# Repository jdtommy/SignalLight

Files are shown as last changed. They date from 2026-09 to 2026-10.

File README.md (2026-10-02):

# SignalLight 🚦

An intelligent status light project using the **Arduino Nano ESP32 (ESP32-S3)** and a **Windows Go (Golang)** desktop companion.

The light indicates your real-time availability:
- 🔴 **RED** (`D2`): In a meeting / Busy (automatically triggered by Zoom or hotkey)
- 🟡 **YELLOW** (`D3`): Not at desk / Away (**Default** on boot and failsafe disconnect)
- 🟢 **GREEN** (`D4`): Free / Available to talk

---

## ⚡ Hardware & Electrical Guide

### ⚠️ Critical Voltage & Wiring Safety Note
> [!WARNING]
> **ESP32-S3 logic levels are strictly 3.3V.**
> Although the Arduino Nano ESP32 board is powered by 5V (via USB-C or `VBUS`), the microcontroller GPIO pins (D2, D3, D4) are **NOT 5V tolerant** (maximum 3.6V).
> 
> If you connect a 10k pull-up resistor from **D3** to **5V**, you will place 5V directly onto an ESP32 GPIO pin. While a 10k resistor limits current, it violates the chip's absolute maximum ratings.
> 
> **Recommended Fix:**
> Connect your 10k pull-up resistor to the **`3V3`** pin on the Arduino header instead of the `5V` pin. This safely pulls D3 HIGH to 3.3V on power-up.

### 💡 Driving 12V LEDs from 3.3V Logic
The ESP32 GPIO pins output 3.3V logic and cannot directly drive 12V LEDs. You should use **Logic-Level N-Channel MOSFETs** (e.g., `IRLZ44N`, `2N7000`, `AO3400`) or a transistor/relay driver module:

```
                      +12V Supply
                           |
                           +--> [ + 12V LED Strip / Lamp ]
                                     |
                                     | (-) Cathode
                                   [ D ]  (Drain)
Arduino Pin (D2/D3/D4) --[100Ω]--> [ G ]  N-Channel Logic MOSFET
                                   [ S ]  (Source)
                                     |
                                    GND
                                     |
             Common GND <------------+------------> Arduino GND
```

#### Yellow Default Circuit:
To keep Yellow ON when the Arduino is disconnected or powered off:
- Place a **10kΩ pull-up resistor** between the **Gate (G)** of the Yellow MOSFET and the **3.3V** rail (or 5V rail if isolated from the GPIO pin by a resistor).
- When the Arduino boots, the firmware immediately drives D3 HIGH and D2/D4 LOW.

### 🖨️ Custom Driver PCB
[`jdtommy-status-indicator-copy-Gerbers-Versionba6d84cb/`](jdtommy-status-indicator-copy-Gerbers-Versionba6d84cb) (fab package) is a small 2-layer PCB export (from [Flux](https://flux.ai)) that replaces the breadboard wiring above with a real board. It mounts an Arduino Nano ESP32 and drives the three LED channels through three `2N3904`-family NPN transistors (instead of the MOSFETs described above — a valid alternative for a modest LED current draw) as low-side switches, with the same Yellow-defaults-on pull-up resistor design:

| Connector | Pin | Signal |
|---|-----|---|
| **CN1** (2-pin, power in) | 1 | GND |
| | 2 | +12V |
| **CN2** (4-pin, LED out) | 1 | +12V (common anode) |
| | 2 | Red cathode (via Q4, driven by D2, R2 = 1kΩ base resistor) |
| | 3 | Yellow cathode (via Q5, driven by D3, R3 = 1kΩ base resistor, **R1 = 10kΩ pull-up to 3.3V**) |
| | 4 | Green cathode (via Q6, driven by D4, R4 = 1kΩ base resistor) |
| **CN3** (2-pin, unpair button) | 1 | GND |
| | 2 | `D5` (firmware's internal pull-up; no external resistor) |

Board outline is roughly **19mm × 45mm**. Wire a normally-open momentary (panel-mount) button to **CN3**; holding it for 10 seconds unpairs the light (see the firmware notes in [ARCHITECTURE.md](ARCHITECTURE.md)).

> [!NOTE]
> **Bare PCB fabrication: ready to order.** `jdtommy-status-indicator-copy-Gerbers-Versionba6d84cb/` has properly formatted Gerber X2 files for all layers, a real Excellon drill file, and an IPC-D-356 bare-board test netlist — this is a standard fab package any house (JLCPCB, PCBWay, OSH Park, etc.) should accept directly. The `jdtommy-status-indicator.edif` netlist and the DXF/SVG plot folders are from the **previous** board revision (no CN3) and aren't needed for ordering.
>
> **Turnkey SMD assembly: not ready — fix the BOM first.** Every vendor BOM CSV in `BOM/` groups R1–R4 into a single line item labeled "1kΩ" (Flux's exporter grouped them by shared footprint and lost the distinct value). The correct values — confirmed in `pick_and_place.csv` — are **R1 = 10kΩ**, **R2/R3/R4 = 1kΩ**. If you submit a BOM as-is, R1 (the Yellow failsafe pull-up) would get placed as 1kΩ instead of 10kΩ: Yellow would still default on, just with ~10x more continuous current through that pull-up than intended. Split R1 into its own line before ordering assembly.
>
> Also note: **U2 (the Arduino Nano ESP32) can't be placed by any SMT line** — it's a whole dev board, not a stocked part, so it needs to be hand-soldered/socketed on regardless of which assembly path you use. The three JST connectors do have real LCSC part numbers (`C158012` for the 2-pin CN1/CN3, `C144395` for the 4-pin CN2) if you want an assembly house to place those.

---

## 📁 Project Structure

```
SignalLight/
├── arduino/
│   ├── SignalLight/
│   │   └── SignalLight.ino      # Arduino C++ sketch (BLE + Serial + Failsafe)
│   └── micropython/
│       └── main.py              # MicroPython equivalent (deprecated, see below)
├── windows/
│   ├── ble/                     # Bluetooth Low Energy (BLE) client
│   ├── hotkey/                  # Global Windows hotkeys (Ctrl+Shift+R/Y/G/A)
│   ├── serial/                  # USB Serial communication fallback
│   ├── server/                  # Web dashboard UI, REST API & Zoom webhook
│   ├── state/                   # State machine (Auto vs Manual, Red/Yellow/Green)
│   ├── zoom/                    # Zero-config Zoom meeting window detector
│   ├── go.mod / go.sum
│   ├── main.go                  # Windows application entry point
│   └── signallight.exe          # Compiled standalone Windows executable
├── installer/
│   └── SignalLight.iss          # Inno Setup script for the per-user installer
├── jdtommy-status-indicator.edif              # Driver PCB netlist (previous revision, no CN3)
├── status-indicator-dxf/                      # Driver PCB plot previews (DXF, not needed for ordering)
├── status-indicator-svg/                      # Driver PCB plot previews (SVG, not needed for ordering)
├── jdtommy-status-indicator-copy-Gerbers-Versionba6d84cb/   # Driver PCB fab package: Gerbers, drill file, BOMs, pick-and-place (see above)
└── README.md
```

---

## 🚀 Part 1: Arduino Firmware Setup

### Option A: Arduino IDE (Recommended)
1. Open the **Arduino IDE**.
2. Install the **Arduino ESP32 Boards** package:
   - Go to `Tools -> Board -> Boards Manager...`
   - Search for **Arduino Nano ESP32** and install.
3. Install the **ArduinoBLE** library:
   - Go to `Sketch -> Include Library -> Manage Libraries...`
   - Search for **ArduinoBLE** and click **Install**.
4. Open [`arduino/SignalLight/SignalLight.ino`](file:///C:/Users/jdtom/dev/SignalLight/arduino/SignalLight/SignalLight.ino).
5. Select `Tools -> Board -> Arduino Nano ESP32` and choose your COM port.
6. Click **Upload**.

### Option B: MicroPython (⚠️ Deprecated / Not Compatible)
[`arduino/micropython/main.py`](file:///C:/Users/jdtom/dev/SignalLight/arduino/micropython/main.py) is kept only as a reference starting point. It has no Auth
characteristic and cannot complete the PAIR/AUTH handshake the Windows app requires, so
pairing from the web dashboard will not work against it. Use Option A.

---

## 🖥️ Part 2: Windows Companion App (in Go)

The Windows app is written in **Go (Golang)**. It features:
1. **Bluetooth Low Energy (BLE)**: Automatically scans for and connects to the Nano ESP32 wirelessly.
2. **Zoom Meeting Detection**: Detects active Zoom meetings automatically with **zero configuration** by monitoring Zoom meeting windows (`ZPContentViewWnd`, `ZPFloatVideoWndClass`, and meeting titles).
3. **Screen Lock Detection:** Automatically detects when you lock your Windows workstation (<kbd>Win</kbd> + <kbd>L</kbd> or idle screen timeout):
   - Automatically switches to 🟡 **YELLOW (Away)** when locked.
   - Automatically restores 🟢 **GREEN (Available)** when unlocked.
   - Priority rule: 🔴 **Zoom Meeting (RED)** always takes precedence over the lock screen.
4. **Global Hotkeys**:
   - <kbd>Ctrl</kbd> + <kbd>Shift</kbd> + <kbd>G</kbd> : Set **GREEN** (Free / Available)
   - <kbd>Ctrl</kbd> + <kbd>Shift</kbd> + <kbd>Y</kbd> : Set **YELLOW** (Away / Not at Desk)
   - <kbd>Ctrl</kbd> + <kbd>Shift</kbd> + <kbd>R</kbd> : Set **RED** (Busy / In Meeting)
   - <kbd>Ctrl</kbd> + <kbd>Shift</kbd> + <kbd>A</kbd> : Set **AUTO** (Resume syncing with Zoom & Lock)
5. **Windows System Tray Icon:** A live, color-coded icon in your taskbar notification area:
   - Dynamic icon color: 🟢 Green, 🟡 Yellow, or 🔴 Red matching current status.
   - Click to open quick menu:
     - View current status & mode
     - Force Green (Available)
     - Force Yellow (Away)
     - Force Red (Busy)
     - Enable Auto Mode (Sync with Zoom & Lock)
     - Open Web Dashboard
     - Exit application
6. **Interactive Web Dashboard**: Automatically assigns an open local port (e.g. `http://localhost:9439`), displayed on startup and saved to config so bookmarks stay valid. Visit the dashboard to pair devices, see real-time status, and control the light from any browser.
7. **Fail-safe Heartbeat**: Continuously pings the Arduino. If your PC goes to sleep or disconnects, the Arduino automatically defaults back to **YELLOW** after 15 seconds.

### Running the App

#### Method 1: Installer (Recommended)
Download `SignalLight-Setup-<version>.exe` from the [latest GitHub Release](https://github.com/jdtommy/SignalLight/releases/latest) and run it. It's signed, needs no admin rights, and installs just for you to `%LOCALAPPDATA%\Programs\SignalLight`. It adds a Start menu shortcut and, unless you untick it, starts SignalLight when you sign in. Uninstall from **Settings → Apps → Installed apps**; it asks whether to keep your pairing.

The installed app has no console window: it lives in the system tray, and its log is at `%LOCALAPPDATA%\SignalLight\signallight.log`. Only one copy runs at a time; launching it again opens the dashboard.

#### Method 2: Running from Source (Development)
This bypasses Windows 11 Smart App Control policies without requiring code-signing certificates:
```powershell
cd C:\Users\jdtom\dev\SignalLight\windows
go run .
```
Or simply double-click [`windows/run.bat`](file:///C:/Users/jdtom/dev/SignalLight/windows/run.bat) or run [`windows/run.ps1`](file:///C:/Users/jdtom/dev/SignalLight/windows/run.ps1).

#### Method 3: Standalone Binary
Download the signed `signallight.exe` from the [latest GitHub Release](https://github.com/jdtommy/SignalLight/releases/latest) and run it from any folder (no install, no startup entry), or build your own from source:
```powershell
cd C:\Users\jdtom\dev\SignalLight\windows
.\signallight.exe
```
> [!NOTE]
> Binaries attached to GitHub Releases are signed with a publicly-trusted Authenticode certificate (via Azure Trusted Signing), so Windows 11 **Smart App Control (SAC)** should allow them without a warning. A binary you compile yourself locally (`go build`/`go run`) is **not** signed — signing requires a live call to Azure with valid credentials — so SAC may still block a self-built `.exe`. If it does, run via `go run .` or download the signed release instead.

#### Command Line Options
| Flag | Default | Description |
|---|---|---|
| `-ble` | `true` | Connect to Arduino over Bluetooth Low Energy |
| `-device` | `""` | BLE advertised device name (overrides config) |
| `-serial` | `""` | Optional USB COM port (e.g. `COM3` or `auto`) if using USB cable |
| `-port` | `""` | Web dashboard port (default: auto-allocated open port, e.g. 9120-9900, saved in config.json) |
| `-interval` | `1s` | Zoom meeting polling interval |

---

## 📋 Future Roadmap & TODO
- [x] **Binary Code Signing**: `signallight.exe` attached to GitHub Releases is signed via [Azure Trusted Signing](https://azure.microsoft.com/en-us/products/artifact-signing) (Public Trust, individual developer), so it should run under Smart App Control without a warning.
- [x] **Automated release signing**: pushing a `vX.Y.Z` tag runs [`.github/workflows/release.yml`](.github/workflows/release.yml), which tests, builds, signs, and verifies `signallight.exe` and the installer, compiles the light's firmware, then attaches them all to a **draft** release. Review the notes and publish. Azure sign-in uses GitHub OIDC, so no Azure secret is stored in GitHub.
- [x] **Installer**: signed per-user Inno Setup installer ([`installer/SignalLight.iss`](installer/SignalLight.iss)), built by the release workflow.

**Firmware updates over Bluetooth** (click-to-update from the dashboard; design and rationale in [docs/FIRMWARE_UPDATES.md](docs/FIRMWARE_UPDATES.md)):
- [x] Prototype BLE transfer throughput on ArduinoBLE: ~47 KB/s with flash writes, so the ~469KB firmware takes ~10s; no NimBLE migration needed
- [x] Firmware reports its version (read-only characteristic `19B10003`); dashboard shows it
- [x] Release workflow compiles the firmware with `arduino-cli` and attaches `signallight-firmware-<version>.bin` + `.sha256`
- [x] Firmware update receiver: chunk/ack protocol, `Update` library, "updating" LED pattern, rollback self-check (a ~500KB update takes ~10s)
- [x] Windows update client + dashboard UI: GitHub check, manual `.bin` upload, progress, retry
- [ ] (Optional) USB recovery flashing via `dfu-util`

**Later:**
- [ ] Firmware signing (CI signs, light verifies before switching)
- [ ] Windows app self-update from GitHub Releases
- [ ] Automatic idle-time firmware updates

---

## 🔗 Optional: Zoom Webhook Integration
The local desktop detector works without any setup. If you also want cloud-level presence notifications from Zoom:
1. Create a **Server-to-Server OAuth** or **Webhook Only** app in the [Zoom App Marketplace](https://marketplace.zoom.us/).
2. Set the Webhook endpoint URL to: `https://<your-public-url>/webhook/zoom`.
3. Subscribe to events: `meeting.started`, `meeting.ended`, `user.presence_status_updated`.
4. Start `signallight.exe` with your secret token:
   ```powershell
   .\signallight.exe -zoom-secret="YOUR_ZOOM_SECRET_TOKEN"
   ```

---

## 📄 License
MIT — see [LICENSE](LICENSE).

## 🔒 Privacy & Code Signing
- [Privacy Policy](PRIVACY.md) — SignalLight collects no data; everything runs locally.
- [Code Signing Policy](CODE_SIGNING_POLICY.md) — official repository, signed artifacts, and release process.

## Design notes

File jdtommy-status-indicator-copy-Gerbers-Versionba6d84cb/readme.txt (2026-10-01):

Project Name: Status Indicator Copy
Project Version: #ba6d84cb
Project Url: https://www.flux.ai/jdtommy/status-indicator-copy~ga

Project Description:
Welcome to your new project. Imagine what you can build here.

Index:

Bottom Copper (Gerber): status-indicator-copy-b_cu.gbr
Bottom Solder Mask (Gerber): status-indicator-copy-b_mask.gbr
Bottom Solder Paste (Gerber): status-indicator-copy-b_paste.gbr
Bottom Silkscreen (Gerber): status-indicator-copy-b_silks.gbr
Board Outline (Gerber): status-indicator-copy-edge_cuts.gbr
Top Copper (Gerber): status-indicator-copy-f_cu.gbr
Top Solder Mask (Gerber): status-indicator-copy-f_mask.gbr
Top Solder Paste (Gerber): status-indicator-copy-f_paste.gbr
Top Silkscreen (Gerber): status-indicator-copy-f_silks.gbr
Drill Holes (Excellon): status-indicator-copy.drl
Electrical Test Netlist (IPC-D-356): status-indicator-copy.d356
Component Positions, for assembly (Pick and Place, CSV): pick_and_place.csv

Bill of Materials: multiple versions are provided optimized for various contract manufacturers:

Bill of Materials (AdvancedCircuits): BOM/jdtommy-status-indicator-copy-BOM-Vba6d84cb-AdvancedCircuits.csv
Bill of Materials (AllPCB): BOM/jdtommy-status-indicator-copy-BOM-Vba6d84cb-AllPCB.csv
Bill of Materials (Elecrow): BOM/jdtommy-status-indicator-copy-BOM-Vba6d84cb-Elecrow.csv
Bill of Materials (Eurocircuits): BOM/jdtommy-status-indicator-copy-BOM-Vba6d84cb-Eurocircuits.csv
Bill of Materials (Flux): BOM/jdtommy-status-indicator-copy-BOM-Vba6d84cb-Flux.csv
Bill of Materials (JLCPCB): BOM/jdtommy-status-indicator-copy-BOM-Vba6d84cb-JLCPCB.csv
Bill of Materials (PCBWay): BOM/jdtommy-status-indicator-copy-BOM-Vba6d84cb-PCBWay.csv
Bill of Materials (Seeed): BOM/jdtommy-status-indicator-copy-BOM-Vba6d84cb-Seeed.csv

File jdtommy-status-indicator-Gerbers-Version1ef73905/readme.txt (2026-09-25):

Project Name: Status Indicator Copy
Project Version: #1ef73905
Project Url: https://www.flux.ai/jdtommy/status-indicator-copy~ga

Project Description:
Welcome to your new project. Imagine what you can build here.

Index:

Bottom Copper (Gerber): status-indicator-copy-b_cu.gbr
Bottom Solder Mask (Gerber): status-indicator-copy-b_mask.gbr
Bottom Solder Paste (Gerber): status-indicator-copy-b_paste.gbr
Bottom Silkscreen (Gerber): status-indicator-copy-b_silks.gbr
Board Outline (Gerber): status-indicator-copy-edge_cuts.gbr
Top Copper (Gerber): status-indicator-copy-f_cu.gbr
Top Solder Mask (Gerber): status-indicator-copy-f_mask.gbr
Top Solder Paste (Gerber): status-indicator-copy-f_paste.gbr
Top Silkscreen (Gerber): status-indicator-copy-f_silks.gbr
Drill Holes (Excellon): status-indicator-copy.drl
Electrical Test Netlist (IPC-D-356): status-indicator-copy.d356
Component Positions, for assembly (Pick and Place, CSV): pick_and_place.csv

Bill of Materials: multiple versions are provided optimized for various contract manufacturers:

Bill of Materials (AdvancedCircuits): BOM/jdtommy-status-indicator-copy-BOM-V1ef73905-AdvancedCircuits.csv
Bill of Materials (AllPCB): BOM/jdtommy-status-indicator-copy-BOM-V1ef73905-AllPCB.csv
Bill of Materials (Elecrow): BOM/jdtommy-status-indicator-copy-BOM-V1ef73905-Elecrow.csv
Bill of Materials (Eurocircuits): BOM/jdtommy-status-indicator-copy-BOM-V1ef73905-Eurocircuits.csv
Bill of Materials (Flux): BOM/jdtommy-status-indicator-copy-BOM-V1ef73905-Flux.csv
Bill of Materials (JLCPCB): BOM/jdtommy-status-indicator-copy-BOM-V1ef73905-JLCPCB.csv
Bill of Materials (PCBWay): BOM/jdtommy-status-indicator-copy-BOM-V1ef73905-PCBWay.csv
Bill of Materials (Seeed): BOM/jdtommy-status-indicator-copy-BOM-V1ef73905-Seeed.csv

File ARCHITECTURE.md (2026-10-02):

# SignalLight — Architecture & Technical Reference

This document details the underlying software architecture, communication protocols, state machines, and concurrency patterns used in **SignalLight**.

---

## 1. Bluetooth Low Energy (BLE) Protocol

The Arduino Nano ESP32 operates as a **GATT Server (Peripheral)**, and the Windows Go desktop companion operates as a **GATT Client (Central)**.

### GATT Service & Characteristics

```
Service: 19B10000-E8F2-537E-4F6C-D104768A1214
 ├── Characteristic 19B10001 (Control) [Read | Write | WriteWithoutResponse | Notify] (1 byte)
 ├── Characteristic 19B10002 (Auth)    [Read | Write | Notify] (UTF-8 String, max 64 bytes)
 ├── Characteristic 19B10003 (Version) [Read] (UTF-8 String, max 32 bytes)
 ├── Characteristic 19B10004 (Update control) [Write] (UTF-8 String, max 100 bytes)
 ├── Characteristic 19B10005 (Update status)  [Read | Notify] (UTF-8 String, max 64 bytes)
 └── Characteristic 19B10006 (Update data)    [Write | WriteWithoutResponse] (max 512 bytes)
```

#### Firmware Update Characteristics (`19B10004`–`19B10006`)
Bluetooth firmware updates: `BEGIN`/`END`/`ABORT` on control, replies and cumulative ACKs on status, sequence-numbered image chunks on data. Only a paired light with an authenticated connection accepts them. A new image must be confirmed by an authenticated connection within 5 minutes of its first boot or the bootloader rolls it back. Full protocol in [docs/FIRMWARE_UPDATES.md](docs/FIRMWARE_UPDATES.md).

#### Version Characteristic (`19B10003`)
Read-only firmware version string, readable without `AUTH` (e.g. `1.2.0`; `dev` for Arduino IDE builds). Set at build time with `-DSIGNALLIGHT_VERSION="x.y.z"` (release builds pass it via `arduino-cli --build-property "compiler.cpp.extra_flags=..."`). Firmware older than this characteristic doesn't have it; the app shows the version as unknown and still connects.

#### Control Characteristic (`19B10001`)
Used for state synchronization, manual commands, and heartbeat pings:
- `'R'` (0x52): In Meeting / Busy.
- `'Y'` (0x59): Away / Workstation Locked.
- `'G'` (0x47): Free / Available.
- `'0'` (0x30): All Off.
- `'P'` (0x50): Heartbeat Ping.
- `'?'` (0x3F): Status Query (returns current color via Serial / BLE read).

#### Auth Characteristic (`19B10002`)
Used for discovery, secure pairing handshakes, and unpairing:
- `PAIR:<FriendlyName>:<SharedSecret>`: Initial pairing command when device is in factory unpaired mode. Returns `PAIR_OK` or error (`ERR:ALREADY_PAIRED`, `ERR:BAD_FORMAT`). `SharedSecret` is generated automatically by the Windows app (random 128-bit value) — the user never sees or types it, only the friendly name.
- `AUTH:<SharedSecret>`: Authentication challenge response sent by Central upon each connection. Returns `AUTH_OK` or `AUTH_FAIL`.
- `UNPAIR`: Factory resets device credentials and reboots into unpaired mode. Returns `UNPAIR_OK`.
- `STATUS?`: Queries device mode. Returns `STATUS:PAIRED` or `STATUS:UNPAIRED`.

---

## 2. Interaction Sequence Diagrams

### Initial Pairing Sequence
```
Central (Windows)                            Peripheral (Arduino Nano ESP32)
       │                                                    │
       │  Scan nearby BLE devices                           │
       │───────────────────────────────────────────────────>│
       │  Advertising: "SignalLight-69F5" (Yellow pulse)    │
       │<───────────────────────────────────────────────────│
       │                                                    │
       │  Connect                                           │
       │───────────────────────────────────────────────────>│
       │  Write (Auth): "PAIR:Office Desk:MySecret123"      │
       │───────────────────────────────────────────────────>│
       │                                                    │ Saves to NVS flash:
       │                                                    │ paired=true, name="Office Desk",
       │                                                    │ secret="MySecret123", active_color='G'
       │  Notify (Auth): "PAIR_OK"                          │
       │<───────────────────────────────────────────────────│
       │                                                    │
       │  Write (Control): 'G'                              │
       │───────────────────────────────────────────────────>│
       │                                                    │ Physical Green LED illuminated
```

---

### Reconnection & State Sync Sequence
```
Central (Windows)                            Peripheral (Arduino Nano ESP32)
       │                                                    │
       │  Connect to "Office Desk" (E8:F6:0A:BE:69:F5)      │
       │───────────────────────────────────────────────────>│
       │                                                    │ isCentralConnected = true
       │  Write (Auth): "AUTH:MySecret123"                  │ isAuthenticated = false (starts 4s timer)
       │───────────────────────────────────────────────────>│
       │                                                    │ Verifies secret against NVS flash
       │                                                    │ isAuthenticated = true
       │                                                    │ applyColor(activeColor) -> Instant Green!
       │  Notify (Auth): "AUTH_OK"                          │
       │<───────────────────────────────────────────────────│
       │                                                    │
       │  Write (Control): Current Desktop State (e.g. 'G') │
       │───────────────────────────────────────────────────>│
       │                                                    │ Confirms activeColor = 'G'
       │                                                    │
       │  Periodic Heartbeat every 3s                       │
       │  Write (Control): 'G'                              │
       │───────────────────────────────────────────────────>│
       │                                                    │ lastHeartbeatTime = millis()
```

---

### Disconnect Grace Period & Watchdog Handling
```
Scenario A: Brief RF Interference (2 seconds)
Central (Windows)                            Peripheral (Arduino Nano ESP32)
       │                                                    │
       │  (Link drop / renegotiation)                       │
       │- - - - - - - - - - - - - - - - - - - - - - - - - ->│
       │                                                    │ blePeripheralDisconnectHandler()
       │                                                    │ disconnectTime = millis()
       │                                                    │ GRACE PERIOD: 45s timer starts.
       │                                                    │ Light STAYS GREEN (No flicker!)
       │  Reconnects after 2s + Auth Handshake              │
       │───────────────────────────────────────────────────>│
       │                                                    │ isAuthenticated = true
       │                                                    │ Active Green maintained seamlessly!

Scenario B: PC Power Off / Prolonged Absence (> 45s)
       │  PC Powers Off                                     │
       │- - - - - - - - - - - - - - - - - - - - - - - - - ->│
       │                                                    │ 45s Disconnect Grace expires.
       │                                                    │ displayedColor switches to YELLOW.
       │                                                    │ (activeColor remains 'G' in flash)
       │                                                    │
       │  PC Boots next morning & reconnects                │
       │───────────────────────────────────────────────────>│
       │  "AUTH:MySecret123"                                │
       │───────────────────────────────────────────────────>│
       │                                                    │ Restores activeColor ('G') immediately!
```

---

## 3. Firmware State Management (`arduino/`)

### Flash (NVS) Layout (`Preferences` namespace: `signallight`)
- `paired` (`bool`): `true` if device has completed initial setup.
- `name` (`String`): Advertised device name (e.g. `"Office Desk"`).
- `secret` (`String`): Shared authorization secret.
- `active_color` (`char`): Last active user color (`'R'`, `'G'`, `'Y'`, `'0'`). Restored on boot.

### Physical Unpair Button (`D5`)
A momentary button from `D5` to GND (`INPUT_PULLUP`, 50ms debounce). Holding it freezes the LEDs on solid red; after 10 seconds the light flashes red 3 times and factory resets (same `factoryReset()` as the `UNPAIR` command). Releasing early cancels and restores `activeColor`. This replaced an older reset-button double-press scheme (`rst_armed` flash flag), which could be falsely triggered by any quick power cycle and wrote to flash on every boot.

### Two-Tier Color Architecture
```
             ┌────────────────────────────────────────────────────────┐
             │                      activeColor                       │
             │           (User / Host Intended State: G/R/Y/0)        │
             └───────────┬────────────────────────────────┬───────────┘
                         │                                │
            Authenticated Handshake               45s Disconnect Timeout
                         │                                │
                         ▼                                ▼
             ┌───────────────────────┐        ┌───────────────────────┐
             │    displayedColor     │        │    displayedColor     │
             │     (Active Color)    │        │       (Yellow)        │
             └───────────────────────┘        └───────────────────────┘
```

---

## 4. Desktop Companion Architecture (`windows/`)

### Concurrency Model
The Go desktop companion coordinates several concurrent goroutines:

```
  ┌─────────────────────────────────────────────────────────────────────────┐
  │                              main() Goroutine                           │
  │                   Initializes subsystems & enters runtime               │
  └───────┬─────────────────┬──────────────────┬─────────────────┬──────────┘
          │                 │                  │                 │
          ▼                 ▼                  ▼                 ▼
   lifecycleLoop()    detectorLoop()     sessionLoop()     httpServer()
     (BLE Central)     (Win32 Zoom)      (Win32 Lock)      (REST / Web)
```

1. **`lifecycleLoop()` (BLE)**: Runs on an OS-locked thread (`runtime.LockOSThread()`) with initialized WinRT COM (`ole.RoInitialize(1)`). Continuously scans, connects, authenticates, and hands connection to `connectionLoop()`.
2. **`connectionLoop()` (BLE)**: Maintains the active link:
   - Evaluates a 3-second ticker for state synchronization and heartbeats.
   - Listens to `c.sendChan` for instantaneous priority color changes from the state manager.
   - Monitors OS link status via `device.Connected()` and abort signals from `SetConnectHandler`.
3. **`detectorLoop()` (Zoom)**: Polls every 1s using Win32 `EnumWindows` and `GetClassNameW` to detect active meeting video windows.
4. **`sessionLoop()` (Lock)**: Creates a hidden Win32 message window and registers for `WTSRegisterSessionNotification`.
5. **`httpServer()` (Web)**: Serves dashboard and REST API on a dynamic port without blocking core workers.

### State Evaluation Priority
The central `StateManager` computes colors in `AUTO` mode using strict hierarchy:
```
1. Not Connected   -> OFF
2. Zoom in Meeting -> RED
3. Screen Locked   -> YELLOW
4. Available       -> GREEN
```
Manual overrides bypass automatic evaluation until returning to `AUTO` via hotkey (<kbd>Ctrl</kbd> + <kbd>Shift</kbd> + <kbd>A</kbd>) or web dashboard.

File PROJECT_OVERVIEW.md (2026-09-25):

# SignalLight — Project Overview

An intelligent, wireless availability and presence indicator for home offices and shared workspaces.

---

## 🎯 Purpose & Philosophy

In modern remote and hybrid workspaces, interruptions during focused work or sensitive video meetings create friction. **SignalLight** solves this by physically broadcasting your real-time status to family members, housemates, or colleagues via a high-visibility, 3-color physical light:

- 🔴 **RED**: In a meeting or actively busy.
- 🟡 **YELLOW**: Away from desk or workstation locked.
- 🟢 **GREEN**: Free, available, and open to conversation.

The system is designed with a **zero-effort, automatic-first** philosophy:
- When a Zoom call starts, the light turns **RED** without touching a button.
- When you lock your screen (<kbd>Win</kbd> + <kbd>L</kbd>) or step away, the light turns **YELLOW**.
- When you unlock your screen, it seamlessly restores **GREEN**.
- Global hotkeys, a system tray icon, and a browser-based web dashboard provide instant manual overrides when needed.

---

## 🏗️ High-Level System Architecture

```
 +-------------------------------------------------------------------+
 |                        WINDOWS WORKSTATION                        |
 |                                                                   |
 |  [Zoom Meeting]     [Screen Lock]     [Global Hotkeys]            |
 |         │                 │                  │                    |
 |         ▼                 ▼                  ▼                    |
 |  ┌─────────────────────────────────────────────────────────────┐  |
 |  │                State Manager (windows/state)                │  |
 |  │     Priority: Zoom (RED) > Lock (YELLOW) > Free (GREEN)     │  |
 |  └──────────────────────────────┬──────────────────────────────┘  |
 |                                 │                                 |
 |                                 ▼                                 |
 |  ┌─────────────────────────────────────────────────────────────┐  |
 |  │              BLE Central Client (windows/ble)               │  |
 |  │        Auto-discovery, Security Handshake, Heartbeats       │  |
 |  └──────────────────────────────┬──────────────────────────────┘  |
 |                                 │                                 |
 |  [Web Dashboard (localhost:9439)] [Tray Icon (Green/Yellow/Red)]  |
 +─────────────────────────────────┼─────────────────────────────────+
                                   │
                                   │ Bluetooth Low Energy (2.4 GHz)
                                   ▼
 +-------------------------------------------------------------------+
 |                    SIGNAL LIGHT HARDWARE UNIT                     |
 |                                                                   |
 |  ┌─────────────────────────────────────────────────────────────┐  |
 |  │              Arduino Nano ESP32 (ESP32-S3)                  │  |
 |  │    - BLE Peripheral Service (19B10000-...)                  │  |
 |  │    - Flash Persistence (NVS) for Pairing & Color Memory     │  |
 |  │    - 45s Disconnect Grace Period & Failsafe Watchdog        │  |
 |  └──────────┬───────────────────┬───────────────────┬──────────┘  |
 |             │ (Pin D2: RED)     │ (Pin D3: YELLOW)  │ (Pin D4: GREEN)
 |             ▼                   ▼                   ▼             |
 |      [MOSFET Driver]     [MOSFET Driver]     [MOSFET Driver]      |
 |             │                   │                   │             |
 |             ▼                   ▼                   ▼             |
 |       🔴 RED LIGHT        🟡 YELLOW LIGHT     🟢 GREEN LIGHT      |
 |                                                                   |
 +-------------------------------------------------------------------+
```

---

## 📦 Repository Structure

```
SignalLight/
├── AGENTS.md                    # Detailed guide and rules for AI assistants
├── ARCHITECTURE.md              # Technical protocols, state diagrams & security
├── PROJECT_OVERVIEW.md          # Comprehensive project description (this file)
├── README.md                    # Quickstart and user manual
│
├── arduino/
│   ├── SignalLight/
│   │   └── SignalLight.ino      # Main Arduino C++ firmware (ESP32-S3 BLE)
│   └── micropython/
│       └── main.py              # MicroPython reference firmware
│
└── windows/
    ├── ble/                     # Windows WinRT BLE client & connection lifecycle
    ├── config/                  # Configuration manager (%APPDATA%\SignalLight)
    ├── hotkey/                  # Windows global hotkey listener
    ├── serial/                  # USB Serial communication fallback
    ├── server/                  # Embedded HTTP server & Web Dashboard UI
    ├── session/                 # Windows workstation lock/unlock detector
    ├── state/                   # Central availability state machine
    ├── third_party/bluetooth/   # Forked bluetooth library with WinRT timeout patch
    ├── tray/                    # Dynamic Windows system tray notification icon
    ├── zoom/                    # Zero-config Win32 Zoom meeting window detector
    ├── main.go                  # Windows entry point
    ├── run.bat / run.ps1        # One-click launch scripts (source execution)
    └── signallight.exe          # Standalone compiled executable
```

---

## 💡 Key Features

### 1. Hands-Free Zoom Sync
No Zoom OAuth or cloud tokens required. The Windows desktop daemon monitors native Zoom video window handles (`ZPContentViewWnd`, `ZPFloatVideoWndClass`) and window titles. As soon as you join a meeting or breakout room, the light switches to Red in less than a second.

### 2. Workstation Lock Detection
Monitors Windows session changes (`WM_WTSSESSION_CHANGE`). When you lock your screen (<kbd>Win</kbd> + <kbd>L</kbd>) or your PC locks after idle timeout, the light switches to Yellow (Away). Returning and unlocking your screen restores Green (Available).

### 3. Resilient BLE with Grace Period
- **45-Second Disconnect Grace:** If Bluetooth experiences momentary RF interference or your laptop renegotiates connection parameters, the light stays solid Green. It only switches to Yellow if disconnected continuously for more than 45 seconds.
- **Instant Reconnection:** When your laptop comes back into range, the Arduino automatically and immediately restores the active color.
- **Fail-Safe Watchdog:** If your PC shuts down, the Arduino detects the absence of heartbeats and falls back to Yellow.

### 4. Interactive Web Dashboard
A modern, responsive web control interface runs on a dynamically allocated local port (e.g. `http://localhost:9439`). Features:
- Real-time live status indicator.
- Single-click color buttons (Green, Yellow, Red, Off).
- Auto mode toggle.
- BLE device scanner, pairing wizard, and unpair controls.

### 5. Multi-Color System Tray Applet
The application lives quietly in the Windows system tray with a dynamic icon colored Green, Yellow, or Red matching your real-time status. Right-clicking provides instant manual controls and direct dashboard access.

---

## ⚡ Hardware Specifications

| Component | Specification |
|---|---|
| **Microcontroller** | Arduino Nano ESP32 (ESP32-S3, Xtensa dual-core, 2.4 GHz BLE) |
| **Operating Voltage** | 5V via USB-C or VBUS; internal MCU logic is **strictly 3.3V** |
| **Logic Outputs** | `D2` (Red), `D3` (Yellow), `D4` (Green) at 3.3V logic level |
| **Power Switching** | Low-side N-Channel Logic MOSFETs (e.g., IRLZ44N, 2N7000, AO3400) |
| **External Light** | 12V LED indicator tower, lamp, or 12V LED strip segments |
| **Safety Circuit** | 10kΩ pull-up resistor from Yellow MOSFET Gate to **3.3V rail** (ensures Yellow on startup/power-off) |

---

## 🚀 Getting Started

1. **Flash the Arduino:** Open [`arduino/SignalLight/SignalLight.ino`](file:///C:/Users/jdtom/dev/SignalLight/arduino/SignalLight/SignalLight.ino) in the Arduino IDE and upload to your Arduino Nano ESP32.
2. **Launch the Windows App:**
   ```powershell
   cd C:\Users\jdtom\dev\SignalLight\windows
   .\run.bat
   ```
3. **Open Dashboard:** Navigate to `http://localhost:9439` (or the port displayed in the console) to complete initial pairing.

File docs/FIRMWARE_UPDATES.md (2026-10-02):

# Firmware Updates over Bluetooth (Design)

Status: **in progress** (see [TODO](#todo)). Goal: update the light's firmware from the Windows app over Bluetooth, with no USB cable and no Wi-Fi setup.

## Decisions

- **Transport:** Bluetooth (BLE), reusing the existing pairing and `AUTH` handshake.
- **Firmware sources:** the latest GitHub Release (normal path), plus a manual `.bin` upload in the dashboard for testing local builds.
- **Updates are click-to-install.** The dashboard shows "firmware vX available" and the user starts the update. No automatic updates for now.
- **Firmware signing is deferred.** The device will verify a SHA-256 of the image, but not a publisher signature yet. See [Later](#later).
- **Windows app self-update is out of scope** for this work.

## What the hardware already gives us

Checked against the installed core (`arduino:esp32` `2.0.18-arduino.5`, board `nano_nora`):

- **Two app slots.** The default partition table (`app3M_fat9M_fact512k_16MB`) has `app0` and `app1` (3MB each) plus `otadata`. The light keeps running from one slot while the new image is written to the other, then reboots into it. An interrupted update leaves the old firmware untouched.
- **Rollback is available.** The bootloader is built with `CONFIG_BOOTLOADER_APP_ROLLBACK_ENABLE=y`. **Catch:** the Arduino core marks a new image as good before `setup()` runs. To make rollback meaningful, the sketch must override `verifyRollbackLater()` to return `true`, then call `esp_ota_mark_app_valid_cancel_rollback()` only after its own self-check passes (BLE started, `loop()` reached). Otherwise the next reboot reverts to the previous image.

## Approach

**Device side: a small custom protocol on the existing ArduinoBLE stack, using the core's `Update` library for flash writes.** The ready-made BLE update libraries ([BLEOTA](https://github.com/gb88/BLEOTA), [NimBLEOta](https://github.com/h2zero/NimBLEOta)) use the NimBLE/Bluedroid stacks, and the sketch uses ArduinoBLE; two BLE stacks can't run at once. Their uploaders are Python/web/mobile, not Go, so the Windows side is custom either way. `Update` handles slot selection, writing, and switching the boot partition. Migrating the sketch to NimBLE stays an option if ArduinoBLE proves too slow (it's lighter and faster, but a bigger change).

**Protocol** (three characteristics on the existing service; device side in `handleOta` and friends in the sketch, app side in `windows/ota`):

| UUID | Name | Properties | Content |
|---|---|---|---|
| `19B10004-…` | Update control | Write | `BEGIN <size> <sha256 hex>`, `END`, `ABORT` |
| `19B10005-…` | Update status | Read, Notify | `READY`, `ACK <seq>`, `OK`, `ABORTED`, `ERR <reason>` |
| `19B10006-…` | Update data | Write, WriteWithoutResponse (512) | `[seq uint32 LE][image bytes]` |

1. `BEGIN <size> <sha256>`: only accepted from a paired light with an authenticated connection (`ERR NOT_AUTHENTICATED` otherwise). The device calls `Update.begin(size)` and replies `READY`.
2. Numbered data chunks sent with `WriteWithoutResponse`. The device requires chunks strictly in order (`ERR SEQ expected N got M` otherwise), writes them with `Update.write`, hashes them, and sends a cumulative `ACK <seq>` every 16 chunks and after the last one. The app keeps at most 32 chunks unacknowledged (see results below). Flow control borrows from Espressif's BLE OTA design and [esp-ota-ble](https://github.com/fl4p/esp-ota-ble).
3. `END`: the device checks the byte count and the SHA-256, then `Update.end()` (which validates the image and sets the boot partition), replies `OK`, and reboots a second later.
4. **Confirm:** the new firmware boots in the bootloader's pending-verify state (`verifyRollbackLater()` returns `true`). The first successful `AUTH` marks it valid. If no authenticated connection arrives within 5 minutes, the light rolls back to the previous firmware and reboots.

Any failure (disconnect, `ABORT`, 15 seconds without data, bad sequence, size or hash mismatch, flash error) aborts the update and leaves the current firmware untouched. The app starts over from `BEGIN`. Notifications are queued by the BLE handlers and sent from `loop()`.

**Must not trust Windows write results.** WinRT can report a BLE write as successful when it never reached the device (see the `writeControl` history in `windows/ble/client.go`). Progress must be driven by the device's acknowledgements and the final hash check, never by write calls returning without error.

**While updating:** the light shows a distinct pattern (e.g. blue on the onboard RGB LED), and ignores color commands and the heartbeat watchdog until it reboots or the update is aborted.

**Firmware publishing:** the release workflow compiles the sketch with `arduino-cli` for `arduino:esp32:nano_nora` and attaches `signallight-firmware-<version>.bin` and its SHA-256 to the draft release. The app compares the light's reported version with the latest release.

## Throughput prototype results (October 2026)

Measured with `arduino/BleThroughputTest` and `windows/cmd/blethroughput`: 128KB per run, Nano ESP32 to Windows 11. Every run delivered all data in order with a matching checksum.

- **Firmware is small:** the current SignalLight image is about **469KB** (`arduino-cli compile --fqbn arduino:esp32:nano_nora`), not the ~1.5MB first assumed.
- **MTU:** Windows negotiated **242**, so each write carries 239 bytes (235 of data after a 4-byte sequence number).

| Mode | KB/s | Time for 469KB |
|---|---|---|
| Acked writes (`Write`) | 2.0 | ~3m50s |
| No-response, window 4 | 7.3 | ~65s |
| No-response, window 8 | 14.8 | ~32s |
| No-response, window 16 | 27.3 | ~17s |
| No-response, window 32 | 54.7 | ~9s |
| No-response, window 32, with flash writes | 47.4 | ~10s |

**Conclusions:**
- **ArduinoBLE is fast enough. No NimBLE migration needed.**
- Speed is bound by the ACK round trip (about 65ms, steady across windows), not by link bandwidth: doubling the window doubles the speed. Acked writes pay that round trip on every write, which is why they are slow.
- Writing to flash costs only 2–13%.
- `WriteWithoutResponse` lost no data, even at window 32. When the device falls behind, the BLE link layer holds the sender back instead of dropping data (the ESP32 transport's 258-byte receive buffer blocks the controller until `loop()` reads it).
- **Use window 32** (device ACKs every 16 chunks) for the real protocol. Larger windows would likely be faster, but ~10s is already enough.

**Lessons for the real protocol:**
- **Put commands and replies on separate characteristics.** ArduinoBLE notifies subscribers of the value a central writes, so on a combined write+notify characteristic, the app receives its own commands back as if they were replies.
- On Windows, `adapter.Enable()` is just `RoInitialize`; calling `RoInitialize` yourself first makes `Enable()` fail with "Incorrect function" (`S_FALSE`).
- Pass `BLE.setLocalName()` a string that outlives `setup()`; ArduinoBLE stores the pointer.
- `Update.write` rejects an image whose first byte isn't `0xE9` (ESP image magic).

## TODO

1. ~~**Prototype throughput.**~~ Done: see results above. ArduinoBLE with a 32-chunk window sends the current firmware in about 10 seconds.
2. ~~**Firmware version reporting.**~~ Done: read-only characteristic `19B10003`, set from the `SIGNALLIGHT_VERSION` build define (`dev` for IDE builds). Release builds can set it with `arduino-cli compile --build-property "compiler.cpp.extra_flags=-DSIGNALLIGHT_VERSION=\"x.y.z\""` (verified). The Windows app discovers characteristics unfiltered so lights on older firmware still connect, and the dashboard shows the version.
3. ~~**CI builds firmware.**~~ Done: the release workflow's `firmware` job compiles with `arduino-cli` 1.5.1, pinned to `arduino:esp32@2.0.18-arduino.5` and `ArduinoBLE@2.1.0` (the versions used for local IDE builds), stamps the version from the tag, checks the version string is in the binary, and attaches `signallight-firmware-<version>.bin` (the app image, which starts with `0xE9`) plus a `.sha256`.
4. ~~**Device update receiver.**~~ Done (protocol above). Hardware test: a 503KB image installed in 9.5s, rebooted, and was confirmed on reconnect (`dev` → `0.9.0-ota-test`). Flashing over USB from the Arduino IDE afterwards still works (back to `dev`). blue onboard LED while updating (the external light keeps its color), rollback unless confirmed by an authenticated connection within 5 minutes. Windows side: the `windows/ota` package (unit-tested against a simulated light) and a test CLI, `go run ./cmd/otaflash <SignalLight.ino.bin>` (quit SignalLight first).
5. ~~**Windows update client and dashboard UI.**~~ Done: the dashboard's firmware panel (shown while a light is paired) shows the light's version, checks GitHub Releases for the newest release with firmware (every 6 hours while the dashboard is open, or on "Check for updates"), and offers "Update to vX", or "Install vX" for a light running a `dev` build. "Install from file…" sends a local `SignalLight.ino.bin`. Downloads are checked against the published `.sha256`. Progress comes from the light's ACKs; after the light reboots, the app waits up to 90 seconds for it to reconnect on the new version and reports the result. A failed update leaves the old firmware running, and clicking Update again starts over. Code: `windows/firmware` (release check and install job), `ble.Client.UpdateFirmware`, `/api/firmware*` in `windows/server`. Tested on hardware both ways: "Install from file…" with a local build, and "Update to 1.2.0" from the published v1.2.0 release (download, checksum, install, reconnect on the new version).
6. **USB recovery fallback (optional).** Flash over USB with `dfu-util` (the board's normal upload tool) if a light ever gets stuck.

## Later

- **Firmware signing.** CI signs the `.bin` (e.g. Ed25519) and the device verifies it against a public key built into the firmware before switching slots, so a compromised PC can't flash malicious firmware. Manual `.bin` uploads would then need signing too, or a developer-mode switch.
- **Windows app self-update** via the same GitHub Releases check.
- **Automatic (idle-time) firmware updates**, once click-to-update has proven reliable.

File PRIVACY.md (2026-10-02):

# Privacy Policy

SignalLight does not collect, transmit, or store any personal data on any server. Everything runs on your own computer and your own Arduino hardware (the only internet access is the firmware update check described below):

- Zoom meeting status is detected locally by scanning window titles on your PC — no Zoom account, API, or OAuth token is used.
- Windows lock/unlock state is detected locally via the OS.
- The web dashboard runs only on `localhost` and is not reachable from the network.
- Pairing info (BLE device address, name, and shared secret) is stored only in a local config file on your own machine (`%APPDATA%\SignalLight\config.json`), never transmitted elsewhere.

**Firmware update checks:** while the web dashboard is open and a light is paired, the app asks GitHub's public releases API (`api.github.com`) for newer light firmware, at most every 6 hours or when you click "Check for updates". When you click Update, it downloads the firmware file from GitHub. These requests carry no personal data, account, or identifier of yours or your light. As with any web request, GitHub sees your IP address; see [GitHub's privacy statement](https://docs.github.com/site-policy/privacy-policies/github-general-privacy-statement). The app makes no other internet requests.

**Optional Zoom webhook integration:** if you choose to configure a Zoom webhook (off by default), your own Zoom account sends meeting/presence events directly to a server you host and control. No third party operated by the SignalLight project is involved in that data flow.

This project has no analytics, crash reporting, or telemetry of any kind.

## Contact

Questions about this policy can be raised via a [GitHub issue](https://github.com/jdtommy/SignalLight/issues) on the project repository.

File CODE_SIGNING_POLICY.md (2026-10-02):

# Code Signing Policy

**Official repository:** https://github.com/jdtommy/SignalLight — this is the only source of authentic SignalLight releases.

**Signed artifacts:** the compiled Windows executable (`signallight.exe`) attached to each [GitHub Release](https://github.com/jdtommy/SignalLight/releases).

**Signing method:** binaries are signed using [Azure Trusted Signing](https://azure.microsoft.com/en-us/products/artifact-signing) under a Public Trust, individual-developer certificate profile. Each signature is issued by a Microsoft-managed CA chain ("Microsoft ID Verified CS EOC CA 04" or successor) and RFC 3161 timestamped, so signatures remain valid independent of the short-lived signing certificate's own expiry.

**Release process:** the repository owner ([@jdtommy](https://github.com/jdtommy)) starts a release by pushing a `v*` tag. The [release workflow](.github/workflows/release.yml) builds and signs `signallight.exe` on GitHub-hosted runners and attaches it to a draft release, which the owner reviews and publishes. The workflow signs in to Azure via GitHub OIDC; Azure only accepts tokens for this repository's `release` environment (restricted to `v*` tags and `main`), and that identity holds only the signer role on this one signing account. No other individuals have release or signing authority.

**Privacy:** see [PRIVACY.md](./PRIVACY.md).

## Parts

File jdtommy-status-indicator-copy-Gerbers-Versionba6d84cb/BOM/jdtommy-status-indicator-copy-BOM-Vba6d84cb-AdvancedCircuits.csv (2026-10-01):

Component Description | QTY | Ref Des | Mfg P/N # | Manufacturer | Distributor P/N #
Wire To Board / Wire To Wire Connector, CONN-TH_B2B-XH-A-LF-SN | 2 | CN1,CN3 | B2B-XH-A(LF)(SN) | JST
Wire To Board / Wire To Wire Connector, CONN-TH_B4B-XH-A-LF-SN | 1 | CN2 | B4B-XH-A(LF)(SN) | JST
Transistor | 3 | Q4,Q5,Q6 | MMBT3904LT1G | onsemi
Resistor, 1kΩ, SMD_1206_3216Metric | 4 | R1,R2,R3,R4 | 1206
Development Board | 1 | U2 | ABX00083 | Arduino

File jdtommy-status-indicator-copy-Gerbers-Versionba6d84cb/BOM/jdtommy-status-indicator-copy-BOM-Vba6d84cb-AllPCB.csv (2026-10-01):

Item # | Ref Des | Qty | Manufacturer | Mfg Part # | Description / Value | Package | Type | Your Instructions / Notes
1 | CN1,CN3 | 2 | JST | B2B-XH-A(LF)(SN) | Wire To Board / Wire To Wire Connector, CONN-TH_B2B-XH-A-LF-SN | CONN-TH_B2B-XH-A-LF-SN
2 | CN2 | 1 | JST | B4B-XH-A(LF)(SN) | Wire To Board / Wire To Wire Connector, CONN-TH_B4B-XH-A-LF-SN | CONN-TH_B4B-XH-A-LF-SN
3 | Q4,Q5,Q6 | 3 | onsemi | MMBT3904LT1G | Transistor
4 | R1,R2,R3,R4 | 4 |  | 1206 | Resistor, 1kΩ, SMD_1206_3216Metric
5 | U2 | 1 | Arduino | ABX00083 | Development Board

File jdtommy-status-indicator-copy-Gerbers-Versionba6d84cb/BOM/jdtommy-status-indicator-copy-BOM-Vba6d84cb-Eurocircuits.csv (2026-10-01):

Reference designators | Quantity | MPN | Manufacturer | Part description | Value | SPN | Supplier | Package
CN1,CN3 | 2 | B2B-XH-A(LF)(SN) | JST | Wire To Board / Wire To Wire Connector, CONN-TH_B2B-XH-A-LF-SN |  |  |  | CONN-TH_B2B-XH-A-LF-SN
CN2 | 1 | B4B-XH-A(LF)(SN) | JST | Wire To Board / Wire To Wire Connector, CONN-TH_B4B-XH-A-LF-SN |  |  |  | CONN-TH_B4B-XH-A-LF-SN
Q4,Q5,Q6 | 3 | MMBT3904LT1G | onsemi | Transistor
R1,R2,R3,R4 | 4 | 1206 |  | Resistor, 1kΩ, SMD_1206_3216Metric | 1kΩ
U2 | 1 | ABX00083 | Arduino | Development Board

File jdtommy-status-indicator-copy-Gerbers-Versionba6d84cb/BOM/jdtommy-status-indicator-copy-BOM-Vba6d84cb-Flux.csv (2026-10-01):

Designator | Quantity | Element UIDs | Part UID | Specification | Part Type | Domain | Compliance | JLCPCB Part Class | Operating Voltage | Operating Temperature | Reliability Target (MTBF) | Role | Role Details | Software | Connector Type | Connector Gender | Connector Pitch | Connector Positions | Connector Rows | Power Requirements | Connectivity | Human Interface | Manufacturing Quantity Target | Manufacturer Part Number | LCSC Part Number | Digi-Key Part Number | Mouser Part Number | Arrow Part Number | Verical Part Number | TME Part Number | HQonline Part Number | McMaster-Carr Part Number | MISUMI Part Number | JLCMC Part Number | Allow Substitutes | Manufacturer Name | Preferred Distributors | Datasheet URL | Machine Datasheet URL | Implementation Details | License | Package or Case Code | Pin Type | Voltage | Voltage Rating | Forward Voltage | Reverse Voltage | Max Reverse Voltage | Diode Type | Mount | Integrated Circuit Type | Breakdown Voltage | Threshold Voltage | Max Output Voltage | Min Output Voltage | Initial Voltage on Reset | Resistance | Resistor Type | Gate Resistance
CN1,CN3 | 2 | 47e84008-c601-4f3a-b58f-c32c934c6a80,95308929-7149-4a89-aa34-0fa4462aa054 | 015f4743-44ed-4b3a-9d98-69469d9853cd | Wire To Board / Wire To Wire Connector, CONN-TH_B2B-XH-A-LF-SN | Wire To Board / Wire To Wire Connector |  |  | Extended Part |  |  |  |  |  |  | Wire To Board / Wire To Wire Connector |  |  |  |  |  |  |  |  | B2B-XH-A(LF)(SN) | C158012 |  |  |  |  |  |  |  |  |  |  | JST |  |  |  |  |  | CONN-TH_B2B-XH-A-LF-SN
CN2 | 1 | 7eb0e0d6-5f81-41a3-be89-9abfb469e76e | 71caedca-597f-4787-9f4a-10f0c7d446c9 | Wire To Board / Wire To Wire Connector, CONN-TH_B4B-XH-A-LF-SN | Wire To Board / Wire To Wire Connector |  |  | Extended Part |  |  |  |  |  |  | Wire-to-board Header |  |  |  |  |  |  |  |  | B4B-XH-A(LF)(SN) | C144395 |  |  |  |  |  |  |  |  |  |  | JST |  |  |  |  |  | CONN-TH_B4B-XH-A-LF-SN
Q4,Q5,Q6 | 3 | 2a75963f-6c38-4d21-b532-2325fb68d228,62a3827b-dc0d-4f5b-8607-0ed4f1ac84f1,ec74f964-8684-4c5c-b2f7-66f7b1d0065c | c89e6e33-04cc-4c16-9a33-027ec5b38bab | Transistor | Transistor |  |  |  |  |  |  |  |  |  |  |  |  |  |  |  |  |  |  | MMBT3904LT1G |  |  |  |  |  |  |  |  |  |  |  | onsemi |  |  |  |  | https://creativecommons.org/licenses/by/4.0/
R1,R2,R3,R4 | 4 | 2b22956f-18e4-4718-b3a1-8fee6a6bca81,a959be78-6751-403f-a606-d422978f1214,ace59b13-9508-45f8-89de-9d7e233f5f63,bbbb6986-8cbc-4d83-ab25-ae1425bfd669 | b67f50a9-ae5e-10ea-9c3c-d377e2ab3b2d | Resistor, 1kΩ, SMD_1206_3216Metric | Resistor |  |  |  |  |  |  |  |  |  |  |  |  |  |  |  |  |  |  | 1206 |  |  |  |  |  |  |  |  |  |  |  |  |  |  |  |  |  |  |  |  | V |  |  |  |  |  |  |  |  |  |  |  | 1kΩ,10kΩ
U2 | 1 | 1bfc9302-2965-411e-a5d1-592852a9415f | cf0bab50-ba54-4581-ad22-8a5ba76df79c | Development Board | Development Board |  |  |  |  |  |  |  |  |  |  |  |  |  |  |  |  |  |  | ABX00083 |  |  |  |  |  |  |  |  |  |  |  | Arduino |  |  |  |  | https://creativecommons.org/licenses/by/4.0/
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

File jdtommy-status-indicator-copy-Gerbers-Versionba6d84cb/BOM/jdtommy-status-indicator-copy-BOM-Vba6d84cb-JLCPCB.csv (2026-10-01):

Comment | Designator | Footprint | JLCPCB Part # | LCSC Part #
B2B-XH-A(LF)(SN) | CN1, CN3 | CONN-TH_B2B-XH-A-LF-SN |  | C158012
B4B-XH-A(LF)(SN) | CN2 | CONN-TH_B4B-XH-A-LF-SN |  | C144395
MMBT3904LT1G | Q4, Q5, Q6
1206 | R1, R2, R3, R4
ABX00083 | U2

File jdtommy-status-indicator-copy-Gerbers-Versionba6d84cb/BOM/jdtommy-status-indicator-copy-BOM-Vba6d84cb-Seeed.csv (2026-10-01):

Designator | Manufacturer Part Number or Seeed SKU | QTY | Link
CN1,CN3 | B2B-XH-A(LF)(SN) | 2
CN2 | B4B-XH-A(LF)(SN) | 1
Q4,Q5,Q6 | MMBT3904LT1G | 3
R1,R2,R3,R4 | 1206 | 4
U2 | ABX00083 | 1

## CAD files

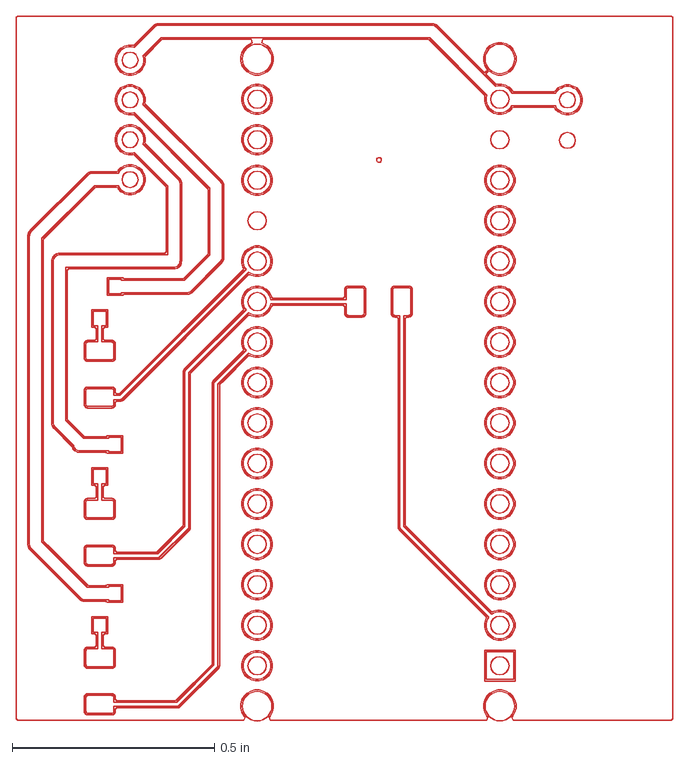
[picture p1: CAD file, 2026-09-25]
status-indicator-dxf/status-indicator-F_Cu.dxf
1.62 x 1.74 in

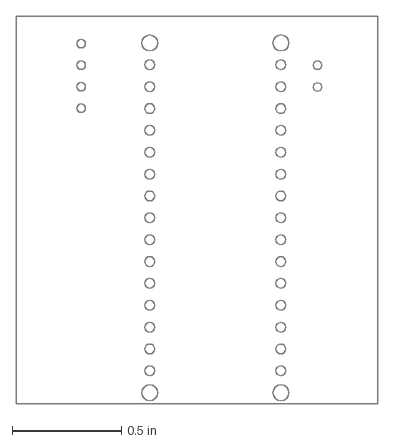
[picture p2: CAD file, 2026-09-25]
status-indicator-dxf/status-indicator_Cuts.dxf
1.65 x 1.77 in

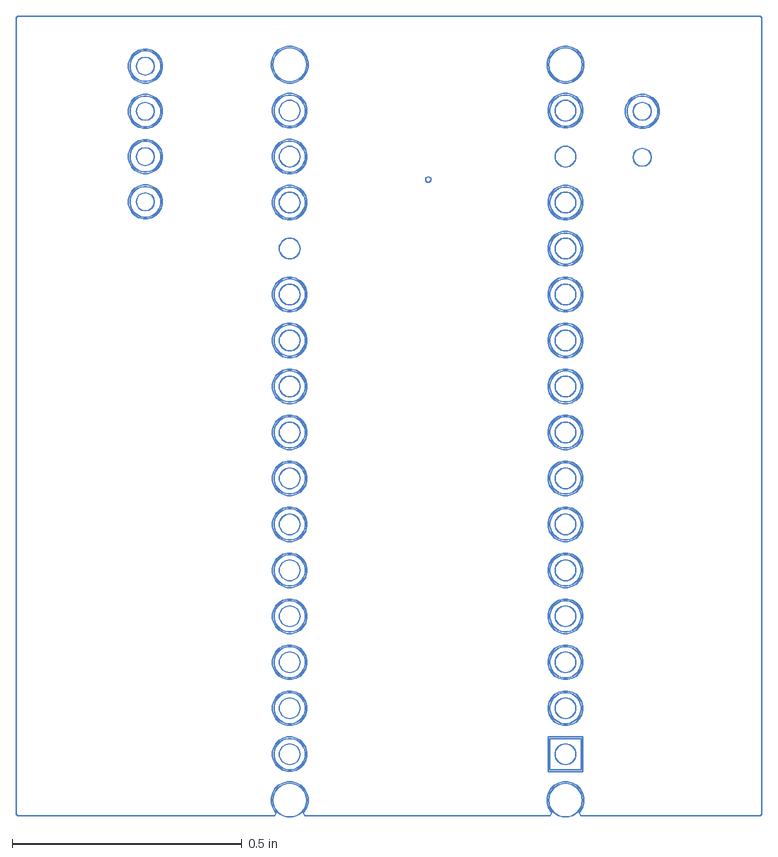
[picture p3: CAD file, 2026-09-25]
status-indicator-dxf/status-indicator-B_Cu.dxf
1.62 x 1.74 in

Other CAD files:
status-indicator-dxf/status-indicator-B_Mask.dxf
status-indicator-dxf/status-indicator-B_Paste.dxf
status-indicator-dxf/status-indicator-B_Silkscreen.dxf
status-indicator-dxf/status-indicator-F_Mask.dxf
status-indicator-dxf/status-indicator-F_Paste.dxf
status-indicator-dxf/status-indicator-F_Silkscreen.dxf

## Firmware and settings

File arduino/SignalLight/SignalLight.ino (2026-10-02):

/*
 * SignalLight - Arduino Nano ESP32 Firmware
 * 
 * Hardware:
 *   - Board: Arduino Nano ESP32 (ESP32-S3)
 *   - Pin D2: RED LED (In Meeting / Busy)
 *   - Pin D3: YELLOW LED (Away / Default)
 *   - Pin D4: GREEN LED (Available / Free)
 *   - Pin D5: Unpair button (momentary, to GND, internal pull-up)
 *
 * Identity & Security:
 *   - Unpaired: Advertises as "SignalLight-[Last 4 MAC]" (e.g. SignalLight-69F5).
 *               Yellow LED pulses to indicate awaiting pairing.
 *   - Paired:   Advertises with custom name (e.g. "Office Desk").
 *               Requires "AUTH:<secret>" handshake within 4s of connection.
 *   - Reset:    Hold the D5 unpair button for 10s (light shows solid red while held,
 *               then flashes red 3 times and factory resets). Releasing early cancels.
 *               Or write "UNPAIR" from the app, or type "FACTORY_RESET" in Serial.
 */

#include <ArduinoBLE.h>
#include <Preferences.h>
#include <Update.h>
#include <esp_mac.h>
#include "esp_ota_ops.h"
#include "mbedtls/sha256.h"

// External LED Pin definitions
const int PIN_RED    = D2;
const int PIN_YELLOW = D3;
const int PIN_GREEN  = D4;
const int PIN_UNPAIR_BUTTON = D5; // Momentary button to GND; INPUT_PULLUP, so pressed reads LOW

// On-board RGB LED is defined by Arduino Nano ESP32 core (LED_RED, LED_GREEN, LED_BLUE: Active-LOW)

// BLE UUIDs
const char* BLE_SERVICE_UUID = "19B10000-E8F2-537E-4F6C-D104768A1214";
const char* BLE_CHAR_UUID    = "19B10001-E8F2-537E-4F6C-D104768A1214";
const char* BLE_AUTH_UUID    = "19B10002-E8F2-537E-4F6C-D104768A1214";
const char* BLE_VERSION_UUID = "19B10003-E8F2-537E-4F6C-D104768A1214";
// Firmware update (OTA) over BLE; protocol in docs/FIRMWARE_UPDATES.md.
// Commands and replies use separate characteristics: ArduinoBLE notifies the
// value a central writes, so a combined one would echo commands back as replies.
const char* BLE_OTA_CONTROL_UUID = "19B10004-E8F2-537E-4F6C-D104768A1214";
const char* BLE_OTA_STATUS_UUID  = "19B10005-E8F2-537E-4F6C-D104768A1214";
const char* BLE_OTA_DATA_UUID    = "19B10006-E8F2-537E-4F6C-D104768A1214";

// Release builds set this from the git tag (e.g. "1.2.0"); IDE builds report "dev".
#ifndef SIGNALLIGHT_VERSION
#define SIGNALLIGHT_VERSION "dev"
#endif

BLEService lightService(BLE_SERVICE_UUID);
BLEByteCharacteristic lightCharacteristic(BLE_CHAR_UUID, BLERead | BLEWrite | BLEWriteWithoutResponse | BLENotify);
BLEStringCharacteristic authCharacteristic(BLE_AUTH_UUID, BLERead | BLEWrite | BLENotify, 64);
// Read-only and not gated by AUTH: the version isn't sensitive, and the app reads it
// before deciding whether a firmware update is available.
BLEStringCharacteristic versionCharacteristic(BLE_VERSION_UUID, BLERead, 32);
BLEStringCharacteristic otaControlCharacteristic(BLE_OTA_CONTROL_UUID, BLEWrite, 100);
BLEStringCharacteristic otaStatusCharacteristic(BLE_OTA_STATUS_UUID, BLERead | BLENotify, 64);
BLECharacteristic otaDataCharacteristic(BLE_OTA_DATA_UUID, BLEWrite | BLEWriteWithoutResponse, 512);

// NVS Persistent Storage
Preferences prefs;
bool isPaired = false;
String deviceName = "";
String sharedSecret = "";

// Must be a global, never modified after BLE.setLocalName(): ArduinoBLE stores the raw
// pointer instead of copying the string, and re-reads it every time advertising is
// rebuilt (each BLE.advertise(), e.g. after a disconnect). A local String in setup()
// is freed when setup() returns, so later advertisements carried a garbage name and
// the dashboard's scan couldn't find the device until it was rebooted.
String advertisedName = "";

// Security & Connection State
BLEDevice activeCentral;
bool isCentralConnected = false;
bool isAuthenticated = false;
unsigned long connectTime = 0;
const unsigned long AUTH_TIMEOUT_MS = 4000;

// Watchdog & Disconnect Timers
const unsigned long HEARTBEAT_TIMEOUT_MS = 60000; // 60s timeout while connected
const unsigned long DISCONNECT_GRACE_MS   = 45000; // 45s grace period on disconnect before turning Yellow
const unsigned long PULSE_CYCLE_MS  = 1000; // Period of the unpaired "awaiting pairing" pulse
const unsigned long PULSE_ON_MS     = 700;  // How much of each cycle the pulse stays lit
unsigned long lastHeartbeatTime = 0;
char activeColor = 'G';     // The desired operational color (survives disconnects)
char displayedColor = ' ';  // The actual color currently illuminated on the LEDs

// Unpair button (hold to factory reset)
const unsigned long UNPAIR_HOLD_MS      = 10000; // Hold time required to factory reset
const unsigned long BUTTON_DEBOUNCE_MS  = 50;
bool unpairHoldActive = false;      // True while the button is held; freezes the display on red
bool buttonDown = false;            // Debounced button state
bool lastRawButtonDown = false;
unsigned long lastRawButtonChange = 0;
unsigned long buttonPressStart = 0;

// Firmware update (OTA) state. BLE event handlers only change this state and call
// Update; all BLE notifications and LED changes happen in loop(), because doing
// them inside a handler can re-enter BLE.poll().
const uint32_t OTA_ACK_EVERY          = 16;     // App keeps up to 32 chunks in flight (see throughput results)
const unsigned long OTA_IDLE_TIMEOUT_MS    = 15000;  // Abort if data stops arriving
const unsigned long OTA_CONFIRM_TIMEOUT_MS = 300000; // Roll back new firmware not confirmed within 5 min
bool otaActive = false;
uint32_t otaSize = 0;
uint32_t otaReceived = 0;
uint32_t otaExpectedSeq = 0;
unsigned long otaLastDataAt = 0;
uint8_t otaExpectedSha[32];
mbedtls_sha256_context otaSha;
bool otaAckPending = false;
uint32_t otaAckSeq = 0;
String otaReplyPending = "";
unsigned long otaRebootAt = 0;   // Non-zero once a verified image is installed; reboot at this time
bool otaDisplayShown = false;
bool firmwarePendingVerify = false; // First boot of an OTA image, not yet confirmed good

// Control the onboard RGB LED (active-LOW logic) and onboard Yellow LED (LED_BUILTIN)
void setOnboardRGB(bool redOn, bool greenOn, bool blueOn) {
  digitalWrite(LED_RED, redOn ? LOW : HIGH);
  digitalWrite(LED_GREEN, greenOn ? LOW : HIGH);
  digitalWrite(LED_BLUE, blueOn ? LOW : HIGH);
  digitalWrite(LED_BUILTIN, (redOn && greenOn && !blueOn) ? HIGH : LOW);
}

void flashLED(int pin, int times, int delayMs) {
  for (int i = 0; i < times; i++) {
    digitalWrite(pin, HIGH);
    if (pin == PIN_RED) {
      setOnboardRGB(true, false, false);
    } else if (pin == PIN_GREEN) {
      setOnboardRGB(false, true, false);
    }
    delay(delayMs);

    digitalWrite(pin, LOW);
    setOnboardRGB(false, false, false);
    delay(delayMs);
  }
}

void applyColor(char c) {
  // While the unpair button is held, the LEDs are frozen on red. Incoming commands
  // still update activeColor (via setActiveColor), so the right color is restored if
  // the hold is cancelled — they just don't reach the LEDs until then. This also keeps
  // the watchdog from overwriting the red mid-hold. A firmware update freezes the
  // display the same way, from BEGIN until the reboot.
  if (unpairHoldActive || otaActive || otaRebootAt != 0) {
    return;
  }
  if (displayedColor == c) {
    return; // Already showing this color; prevent flicker, flash wear, and log spam
  }
  displayedColor = c;
  
  digitalWrite(PIN_RED, LOW);
  digitalWrite(PIN_YELLOW, LOW);
  digitalWrite(PIN_GREEN, LOW);

  switch (c) {
    case 'R':
      digitalWrite(PIN_RED, HIGH);
      setOnboardRGB(true, false, false); // Onboard RED
      Serial.println("[State] -> RED (In Meeting)");
      break;
    case 'G':
      digitalWrite(PIN_GREEN, HIGH);
      setOnboardRGB(false, true, false); // Onboard GREEN
      Serial.println("[State] -> GREEN (Available)");
      break;
    case 'Y':
    default:
      digitalWrite(PIN_YELLOW, HIGH);
      setOnboardRGB(true, true, false);  // Onboard YELLOW (Red + Green)
      Serial.println("[State] -> YELLOW (Away / Disconnected)");
      displayedColor = 'Y';
      break;
    case '0':
      setOnboardRGB(false, false, false); // All OFF
      Serial.println("[State] -> ALL OFF");
      break;
  }

  lightCharacteristic.writeValue((byte)displayedColor);
}

void setActiveColor(char c) {
  c = toupper(c);
  if (c != 'R' && c != 'G' && c != 'Y' && c != '0') {
    return;
  }
  activeColor = c;

  // Persist active color so reboots/brownouts hold the same state seamlessly
  if (isPaired) {
    prefs.begin("signallight", false);
    if (prefs.getChar("active_color", ' ') != activeColor) {
      prefs.putChar("active_color", activeColor);
    }
    prefs.end();
  }

  applyColor(activeColor);
}

void factoryReset() {
  Serial.println("[Reset] Wiping settings from flash...");
  prefs.begin("signallight", false);
  prefs.clear();
  prefs.end();

  // Flash RED 3 times
  digitalWrite(PIN_YELLOW, LOW);
  digitalWrite(PIN_GREEN, LOW);
  flashLED(PIN_RED, 3, 150);

  Serial.println("[Reset] Factory reset complete. Deinitializing BLE and rebooting...");
  delay(300);
  BLE.end();
  delay(100);
  ESP.restart();
}

void showUnpairHoldRed() {
  digitalWrite(PIN_YELLOW, LOW);
  digitalWrite(PIN_GREEN, LOW);
  digitalWrite(PIN_RED, HIGH);
  setOnboardRGB(true, false, false);
}

// Non-blocking: called every loop(). Hold the button for UNPAIR_HOLD_MS to factory
// reset; the light shows solid red the whole time it's held. Releasing early cancels
// and restores whatever color is currently active.
void handleUnpairButton() {
  unsigned long t = millis();
  bool rawDown = digitalRead(PIN_UNPAIR_BUTTON) == LOW;

  if (rawDown != lastRawButtonDown) {
    lastRawButtonDown = rawDown;
    lastRawButtonChange = t;
  }

  if (t - lastRawButtonChange >= BUTTON_DEBOUNCE_MS && rawDown != buttonDown) {
    buttonDown = rawDown;
    if (buttonDown) {
      buttonPressStart = t;
      unpairHoldActive = true;
      showUnpairHoldRed();
      Serial.println("[Reset] Unpair button held. Keep holding for 10s to factory reset...");
    } else if (unpairHoldActive) {
      unpairHoldActive = false;
      displayedColor = ' '; // Force applyColor to re-drive the LEDs
      applyColor(isPaired ? activeColor : 'Y');
      Serial.println("[Reset] Unpair button released early. Cancelled.");
    }
  }

  if (unpairHoldActive && t - buttonPressStart >= UNPAIR_HOLD_MS) {
    Serial.println("[Reset] Unpair button held for 10s. Factory resetting...");
    // Turn the solid red off briefly so the 3 confirmation flashes read as distinct.
    digitalWrite(PIN_RED, LOW);
    setOnboardRGB(false, false, false);
    delay(400);
    factoryReset(); // Flashes red 3 times, wipes flash, reboots unpaired
  }
}

// The core marks a newly installed image as good before setup() runs unless this
// returns true. Returning true makes the sketch confirm it itself (on the first
// authenticated connection, see processAuthMessage), so a firmware that boots but
// can't talk BLE gets rolled back. Defined weak in the core's C code, hence extern "C".
extern "C" bool verifyRollbackLater() {
  return true;
}

bool parseSha256Hex(const char* hex, uint8_t out[32]) {
  if (strlen(hex) != 64) {
    return false;
  }
  for (int i = 0; i < 32; i++) {
    char byteStr[3] = {hex[2 * i], hex[2 * i + 1], 0};
    char* end;
    out[i] = (uint8_t)strtoul(byteStr, &end, 16);
    if (*end != 0) {
      return false;
    }
  }
  return true;
}

// Stops an update in progress without installing anything. Safe to call from
// BLE handlers: no BLE calls or LED changes here (loop() restores the display).
void otaReset() {
  if (otaActive) {
    Update.abort();
    mbedtls_sha256_free(&otaSha);
  }
  otaActive = false;
  otaAckPending = false;
}

void otaFail(const String& reason) {
  Serial.println("[OTA] Failed: " + reason);
  otaReset();
  otaReplyPending = "ERR " + reason;
}

void otaBegin(const String& cmd) {
  unsigned long size = 0;
  char shaHex[65] = {0};
  if (sscanf(cmd.c_str(), "BEGIN %lu %64s", &size, shaHex) != 2 || size == 0 || !parseSha256Hex(shaHex, otaExpectedSha)) {
    otaReplyPending = "ERR BAD_BEGIN";
    return;
  }
  otaReset();
  if (!Update.begin(size)) {
    otaReplyPending = String("ERR BEGIN ") + Update.errorString();
    return;
  }
  mbedtls_sha256_init(&otaSha);
  mbedtls_sha256_starts_ret(&otaSha, 0);
  otaActive = true;
  otaSize = size;
  otaReceived = 0;
  otaExpectedSeq = 0;
  otaLastDataAt = millis();
  Serial.printf("[OTA] Update started: %lu bytes\n", size);
  otaReplyPending = "READY";
}

void otaEnd() {
  if (!otaActive) {
    otaReplyPending = "ERR NOT_ACTIVE";
    return;
  }
  if (otaReceived != otaSize) {
    otaFail("SIZE " + String(otaReceived) + "/" + String(otaSize));
    return;
  }
  uint8_t digest[32];
  mbedtls_sha256_finish_ret(&otaSha, digest);
  if (memcmp(digest, otaExpectedSha, sizeof(digest)) != 0) {
    otaFail("SHA_MISMATCH");
    return;
  }
  mbedtls_sha256_free(&otaSha);
  // Validates the image and makes it the boot partition for the next restart.
  if (!Update.end()) {
    otaActive = false; // Update already cleaned up; don't abort it again
    otaReplyPending = String("ERR END ") + Update.errorString();
    Serial.println("[OTA] Failed: " + otaReplyPending);
    return;
  }
  otaActive = false;
  otaRebootAt = millis() + 1000; // Give the OK notification time to go out
  Serial.println("[OTA] Image verified and installed. Rebooting...");
  otaReplyPending = "OK";
}

void onOtaControlWritten(BLEDevice, BLECharacteristic) {
  String cmd = otaControlCharacteristic.value();
  cmd.trim();
  // Only a paired light with an authenticated app accepts firmware; otherwise any
  // nearby BLE device could flash it.
  if (!isPaired || !isAuthenticated) {
    otaReplyPending = "ERR NOT_AUTHENTICATED";
    return;
  }
  if (otaRebootAt != 0) {
    otaReplyPending = "ERR REBOOTING";
  } else if (cmd.startsWith("BEGIN ")) {
    otaBegin(cmd);
  } else if (cmd == "END") {
    otaEnd();
  } else if (cmd == "ABORT") {
    otaReset();
    otaReplyPending = "ABORTED";
  } else {
    otaReplyPending = "ERR UNKNOWN_COMMAND";
  }
}

// Chunk format: [seq uint32 little-endian][image bytes].
void onOtaDataWritten(BLEDevice, BLECharacteristic c) {
  if (!otaActive) {
    return;
  }
  int len = c.valueLength();
  if (len < 5) {
    otaFail("SHORT_CHUNK");
    return;
  }
  const uint8_t* v = c.value();
  uint32_t seq = (uint32_t)v[0] | ((uint32_t)v[1] << 8) | ((uint32_t)v[2] << 16) | ((uint32_t)v[3] << 24);
  if (seq != otaExpectedSeq) {
    otaFail("SEQ expected " + String(otaExpectedSeq) + " got " + String(seq));
    return;
  }
  size_t n = len - 4;
  if (otaReceived + n > otaSize) {
    otaFail("TOO_MUCH_DATA");
    return;
  }
  if (Update.write((uint8_t*)(v + 4), n) != n) {
    otaFail(String("WRITE ") + Update.errorString());
    return;
  }
  mbedtls_sha256_update_ret(&otaSha, v + 4, n);
  otaReceived += n;
  otaExpectedSeq++;
  otaLastDataAt = millis();
  if (otaExpectedSeq % OTA_ACK_EVERY == 0 || otaReceived == otaSize) {
    otaAckSeq = seq;
    otaAckPending = true;
  }
}

// Called every loop(): sends queued replies, enforces the idle timeout, shows the
// update on the LEDs, reboots after a successful update, and rolls back new
// firmware that was never confirmed.
void handleOta() {
  if (otaAckPending) {
    otaAckPending = false;
    otaStatusCharacteristic.writeValue("ACK " + String(otaAckSeq));
  }
  if (otaReplyPending.length() > 0) {
    Serial.println("[OTA] -> " + otaReplyPending);
    otaStatusCharacteristic.writeValue(otaReplyPending);
    otaReplyPending = "";
  }
  if (otaActive && millis() - otaLastDataAt > OTA_IDLE_TIMEOUT_MS) {
    otaFail("TIMEOUT");
  }

  bool showOta = otaActive || otaRebootAt != 0;
  if (showOta && !otaDisplayShown) {
    otaDisplayShown = true;
    setOnboardRGB(false, false, true); // Onboard blue; external light keeps its color
  } else if (!showOta && otaDisplayShown) {
    otaDisplayShown = false;
    displayedColor = ' '; // Force applyColor to re-drive the LEDs
    applyColor(isPaired ? activeColor : 'Y');
  }

  if (otaRebootAt != 0 && (long)(millis() - otaRebootAt) >= 0) {
    BLE.end();
    delay(100);
    ESP.restart();
  }

  if (firmwarePendingVerify && millis() > OTA_CONFIRM_TIMEOUT_MS) {
    Serial.println("[OTA] New firmware was never confirmed by an authenticated connection. Rolling back...");
    esp_ota_mark_app_invalid_rollback_and_reboot();
  }
}

void processControlCommand(char cmd) {
  if (isPaired && !isAuthenticated) {
    Serial.println("[Security] Control command ignored: not authenticated.");
    return;
  }

  cmd = toupper(cmd);
  lastHeartbeatTime = millis();

  switch (cmd) {
    case 'R':
    case 'Y':
    case 'G':
    case '0':
      // Explicit log of the raw command + its source: helps distinguish an
      // intentional color change (hotkey/dashboard/heartbeat resync) from the
      // watchdog's own distinct "[Watchdog] ... Reverting to YELLOW" log lines below.
      Serial.print("[Control] Received explicit command from host: ");
      Serial.println(cmd);
      setActiveColor(cmd);
      break;
    case 'P':
      // Heartbeat ping: If previously fallen back to Yellow due to disconnect/watchdog, restore activeColor
      if (displayedColor != activeColor) {
        applyColor(activeColor);
      }
      break;
    case '?':
      Serial.print("STATUS:");
      Serial.println(displayedColor);
      break;
    default:
      break;
  }
}
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
void loop() {
  unsigned long now = millis();

  // 1. Unpair button (hold 10s to factory reset)
  handleUnpairButton();
  handleOta();

  // 2. Poll BLE stack
  BLE.poll();

  // 3. Restart advertising safely after disconnect (outside the callback)
  // disconnectTime is set by blePeripheralDisconnectHandler during BLE.poll() just
  // above, i.e. possibly later in this very iteration than the stale `now` above —
  // use a fresh read so "now - disconnectTime" can't underflow (see step 9's comment).
  if (needAdvertise && (millis() - disconnectTime >= 200)) {
    needAdvertise = false;
    Serial.println("[BLE] Resuming advertising...");
    BLE.advertise();
  }

  // 4. Security Timeout Check (disconnect central if it didn't authenticate in 4s)
  // connectTime is set by blePeripheralConnectHandler during BLE.poll() just above,
  // possibly later in this same iteration than the stale `now` — use a fresh read so
  // this can't underflow and spuriously kick a central the instant it connects.
  if (isCentralConnected && isPaired && !isAuthenticated) {
    if (millis() - connectTime > AUTH_TIMEOUT_MS) {
      Serial.println("[Security] Auth timeout exceeded! Disconnecting central.");
      if (activeCentral && activeCentral.connected()) {
        activeCentral.disconnect();
      }
    }
  }

  // 5. Handle Auth Characteristic
  if (authCharacteristic.written()) {
    String msg = authCharacteristic.value();
    processAuthMessage(msg);
  }

  // 6. Handle Control Characteristic
  if (lightCharacteristic.written()) {
    byte val = lightCharacteristic.value();
    processControlCommand((char)val);
  }

  // 7. Handle USB Serial Commands
  if (Serial.available() > 0) {
    String input = Serial.readStringUntil('\n');
    input.trim();
    if (input.equalsIgnoreCase("FACTORY_RESET") || input.equalsIgnoreCase("UNPAIR")) {
      factoryReset();
    } else if (input.length() > 0) {
      char firstChar = toupper(input.charAt(0));
      processControlCommand(firstChar);
    }
  }

  // 8. Visual Pulse when Unpaired and Awaiting Connection (paused while the unpair
  // button is held, since this writes the LEDs directly rather than via applyColor)
  if (!isPaired && !isCentralConnected && !unpairHoldActive) {
    unsigned long cycle = now % PULSE_CYCLE_MS;
    if (cycle < PULSE_ON_MS) {
      digitalWrite(PIN_YELLOW, HIGH);
      setOnboardRGB(true, true, false); // Onboard Yellow (Red + Green)
    } else {
      digitalWrite(PIN_YELLOW, LOW);
      setOnboardRGB(false, false, false); // Onboard OFF
    }
  }

  // 9. Failsafe Watchdog & Disconnect Timeout
  //
  // Use a freshly-read timestamp here rather than the `now` snapshot taken at the top
  // of loop(), instead of just relying on it like the other checks above. lastHeartbeatTime
  // can be updated by step 6 (processControlCommand, via a fresh millis() call) LATER in
  // this same iteration than when `now` was captured. Since these are unsigned long, if
  // that later update ends up numerically greater than the stale `now` (which happens
  // whenever BLE.poll() or anything else above takes even 1ms), "now - lastHeartbeatTime"
  // underflows and wraps around to a huge value — far past HEARTBEAT_TIMEOUT_MS — causing
  // an immediate, spurious YELLOW revert in the very same instant a command was just
  // successfully received. This was a real, observed bug: the watchdog log line and the
  // "[Control] Received..." log line for the command that supposedly timed out would show
  // the identical millisecond timestamp. A fresh read here guarantees it's never earlier
  // than any update lastHeartbeatTime/disconnectTime could have received this iteration.
  if (isPaired) {
    unsigned long watchdogNow = millis();
    if (isCentralConnected) {
      // While connected: timeout if no heartbeat received for 60s
      if (watchdogNow - lastHeartbeatTime > HEARTBEAT_TIMEOUT_MS) {
        if (displayedColor != 'Y') {
          Serial.println("[Watchdog] Heartbeat timeout while connected. Reverting to YELLOW.");
          applyColor('Y');
        }
      }
    } else {
      // While disconnected: hold previous color for DISCONNECT_GRACE_MS (45s), then turn Yellow
      if (watchdogNow - disconnectTime > DISCONNECT_GRACE_MS) {
        if (displayedColor != 'Y') {
          Serial.println("[Watchdog] Disconnect grace period expired. Reverting to YELLOW.");
          applyColor('Y');
        }
      }
    }
  }
}

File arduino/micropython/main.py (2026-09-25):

"""
SignalLight - MicroPython for Arduino Nano ESP32 (ESP32-S3)

*** DEPRECATED / NOT MAINTAINED ***
This file only implements the Control characteristic (19B10001). It has no Auth
characteristic (19B10002) at all, so it cannot complete the PAIR/AUTH handshake the
current Windows companion app and Arduino .ino firmware use (see ARCHITECTURE.md).
Pairing from the Windows app's web dashboard will not work against this firmware.
It is kept only as a reference for a from-scratch MicroPython port and is not a
supported alternative to arduino/SignalLight/SignalLight.ino.

Hardware:
  - D2 (GPIO 5): RED LED
  - D3 (GPIO 6): YELLOW LED (Default ON)
  - D4 (GPIO 7): GREEN LED
"""

import time
import machine
import bluetooth
from micropython import const

# BLE Event constants
_IRQ_CENTRAL_CONNECT = const(1)
_IRQ_CENTRAL_DISCONNECT = const(2)
_IRQ_GATTS_WRITE = const(3)

# Nordic UART / Custom UUIDs
_SERVICE_UUID = bluetooth.UUID("19B10000-E8F2-537E-4F6C-D104768A1214")
_CHAR_UUID = bluetooth.UUID("19B10001-E8F2-537E-4F6C-D104768A1214")

# Setup Pins (Arduino Nano ESP32 D2, D3, D4 map to GPIO pins 5, 6, 7 in ESP32-S3 default mapping)
# Note: Adjust pin numbers if your MicroPython firmware uses board-labeled pin names.
try:
    pin_red = machine.Pin("D2", machine.Pin.OUT)
    pin_yellow = machine.Pin("D3", machine.Pin.OUT)
    pin_green = machine.Pin("D4", machine.Pin.OUT)
except ValueError:
    # Standard ESP32 GPIO fallback for Nano ESP32
    pin_red = machine.Pin(5, machine.Pin.OUT)
    pin_yellow = machine.Pin(6, machine.Pin.OUT)
    pin_green = machine.Pin(7, machine.Pin.OUT)

current_color = 'Y'
last_heartbeat = time.ticks_ms()
TIMEOUT_MS = 15000

def apply_color(c):
    global current_color
    current_color = c.upper()
    
    pin_red.value(0)
    pin_yellow.value(0)
    pin_green.value(0)
    
    if current_color == 'R':
        pin_red.value(1)
        print("[State] RED (In Meeting)")
    elif current_color == 'G':
        pin_green.value(1)
        print("[State] GREEN (Available)")
    else:
        pin_yellow.value(1)
        current_color = 'Y'
        print("[State] YELLOW (Away / Default)")

class BLELight:
    def __init__(self, ble, name="SignalLight"):
        self._ble = ble
        self._ble.active(True)
        self._ble.irq(self._irq)
        
        SERVICE = (
            _SERVICE_UUID,
            ((_CHAR_UUID, bluetooth.FLAG_READ | bluetooth.FLAG_WRITE | bluetooth.FLAG_NOTIFY),),
        )
        ((self._handle,),) = self._ble.gatts_register_services((SERVICE,))
        self._connections = set()
        self._advertise(name)
        
    def _irq(self, event, data):
        global last_heartbeat
        if event == _IRQ_CENTRAL_CONNECT:
            conn_handle, _, _ = data
            self._connections.add(conn_handle)
            print("[BLE] Connected")
            last_heartbeat = time.ticks_ms()
        elif event == _IRQ_CENTRAL_DISCONNECT:
            conn_handle, _, _ = data
            self._connections.remove(conn_handle)
            print("[BLE] Disconnected")
            self._advertise()
        elif event == _IRQ_GATTS_WRITE:
            conn_handle, value_handle = data
            if value_handle == self._handle:
                value = self._ble.gatts_read(self._handle)
                if value:
                    cmd = chr(value[0]).upper()
                    last_heartbeat = time.ticks_ms()
                    if cmd in ('R', 'G', 'Y'):
                        apply_color(cmd)

    def _advertise(self, name="SignalLight"):
        name_bytes = bytes(name, "UTF-8")
        payload = bytearray(
            b"\x02\x01\x06" +
            bytes([len(name_bytes) + 1, 0x09]) +
            name_bytes
        )
        self._ble.gap_advertise(100000, payload)
        print(f"[BLE] Advertising as {name}")

def main():
    apply_color('Y')
    ble = bluetooth.BLE()
    light = BLELight(ble)
    
    global last_heartbeat
    print("SignalLight MicroPython started.")
    
    while True:
        # Failsafe watchdog
        if time.ticks_diff(time.ticks_ms(), last_heartbeat) > TIMEOUT_MS:
            if current_color != 'Y':
                print("[Watchdog] Timeout. Defaulting to YELLOW.")
                apply_color('Y')
            last_heartbeat = time.ticks_ms()
        time.sleep_ms(200)

if __name__ == "__main__":
    main()

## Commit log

2026-09-14 Initial commit: SignalLight with BLE, Zoom detector, and Arduino firmware
2026-09-24 feat: add pairing UI, dynamic web port, WinRT crash fix, and firmware stability
    - Arduino: improve reset button handling, fix onboarding RGB sync, and add heartbeat fail-safe
    - BLE: vendor and patch tinygo bluetooth to fix Windows WinRT 0xc0000005 access violation crash on disconnect
    - Web/API: add device scanning, pairing with PIN, unpairing flow, and real-time disconnected bulb state
    - Server: allocate dynamic open port (9120-9900) instead of 8080 and persist in config.json
    - Desktop: add Windows session lock watcher, global hotkeys (Ctrl+Shift+G/Y/R/A), and tray icon
    - Tests & Docs: add unit tests for port allocation and Zoom detector, and update README
    [SignalLight.ino]
2026-09-25 fix: critical BLE/security bugs, config crash, test isolation, and yellow-light false-positive lock detection
    Critical fixes:
    - BLE auth handshake failed open: an empty/garbled/error auth response fell
    through to authenticated=true. Now requires an explicit AUTH_OK.
    - A goroutine spawned right after pairing skipped WinRT thread/COM init
    (LockOSThread + RoInitialize), unlike every other call path in the BLE
    client. Moved the setup into runSession itself so it's always safe.
    - config.Load() returned nil on a corrupt/unreadable config.json, crashing
    main.go on startup instead of degrading to unpaired. Now always returns a
    safe default.
    - The config test resolved through the real GetCo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
    [SignalLight.ino, main.py]
2026-09-25 fix: firmware millis() underflow causing spurious yellow reverts; soften BLE reconnect handling; add PCB fab files and MIT license
    Root-caused and fixed the actual cause of the recurring "goes yellow, then
    self-corrects" bug: loop() snapshots `now = millis()` once at the top, before
    BLE.poll(). Three checks later in the same pass compared that stale `now`
    against timestamps (lastHeartbeatTime, connectTime, disconnectTime) that can
    get updated to a fresher value later in the very same iteration, by a BLE
    event handler or by processing an incoming control write. Since these are
    unsigned long, that inverted subtraction underflows to a huge value, blowing
    past every timeout threshold instantly.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
    [jdtommy-status-indicator-copy-BOM-V1ef73905-AdvancedCircuits.csv, jdtommy-status-indicator-copy-BOM-V1ef73905-AllPCB.csv, jdtommy-status-indicator-copy-BOM-V1e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]
2026-09-25 docs: mark code signing complete, document Azure Trusted Signing setup
    signallight.exe on the v1.0.0 GitHub Release is now signed via Azure
    Trusted Signing (Public Trust, individual developer certificate profile,
    issued by Microsoft ID Verified CS EOC CA 04). Updated the roadmap,
    Method 2 instructions, and CODE_SIGNING_POLICY.md to reflect the actual
    signing method and process instead of describing it as a future TODO.
    Signing is currently a manual step tied to the maintainer's own Azure
    session; automating it into a release pipeline is tracked as a new
    roadmap item.
2026-09-26 feat: auto-generate the BLE pairing secret instead of asking the user for one
    The shared secret is only ever used programmatically between the Windows
    app and the Arduino (written to config.json, never re-typed by a human
    after pairing) — there was no real reason to make the user invent and type
    one during pairing. The pairing dialog now only asks for a friendly device
    name; the app generates a random 128-bit secret itself (generateSecret(),
    hex-encoded so it can't confuse the Arduino's PAIR:<name>:<secret> parsing).
    This is also a real security improvement: a random 128-bit value is far
    stronger than anything a person would type in (short, memorable, guessable
    PINs/passwords), with zero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
2026-10-01 feat: hold-to-unpair button on D5; fix garbled BLE advertising name
    Unpair button: a momentary button from D5 to GND (INPUT_PULLUP, 50ms
    debounce) replaces the reset-button double-press. Holding it freezes the
    LEDs on solid red; after 10s the light flashes red 3 times and factory
    resets. Releasing early cancels and restores activeColor. The old
    double-press scheme wrote an rst_armed flag to flash on every boot and
    could be falsely triggered by any quick power cycle (e.g. a USB
    unplug/replug), wiping a valid pairing.
    Advertising name fix: setup() passed a local String's c_str() to
    BLE.setLocalName(). ArduinoBLE stores that raw pointer and re-reads it
    every time advertising is rebuilt, so aft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
    [SignalLight.ino]
2026-10-01 hw: add CN3 unpair-button header to the driver PCB (Versionba6d84cb)
    New board revision adds CN3, a 2-pin JST XH header (same part as CN1)
    for a panel-mount momentary button: pin 2 to D5, pin 1 to GND, matching
    the firmware's hold-10s-to-unpair button. Verified against the IPC-356
    netlist: the only connectivity change is D5 going from unconnected to
    CN3-2 plus CN3-1 on GND; board outline is unchanged; drill count grows
    41 -> 44 (CN3's two pins plus one rerouted GND via).
    Replaces the Version1ef73905 fab package. README updated with the new
    folder, CN3 pinout, and a note that the .edif and DXF/SVG plots are
    from the previous revision.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
    [jdtommy-status-indicator-copy-BOM-Vba6d84cb-AdvancedCircuits.csv, jdtommy-status-indicator-copy-BOM-Vba6d84cb-AllPCB.csv, jdtommy-status-indicator-copy-BOM-Vba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]
2026-10-02 ci: build, sign, and draft releases from GitHub Actions
    Pushing a v* tag now builds signallight.exe on a Windows runner, runs the
    Go tests, signs it via Azure Trusted Signing, verifies the signature is
    valid and timestamped, and attaches it to a draft release for review.
    "Run workflow" does the same build-and-sign and uploads the exe as an
    artifact without releasing.
    Azure sign-in uses GitHub OIDC (no stored Azure secret). Azure only trusts
    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
2026-10-02 feat: signed per-user Inno Setup installer with run-at-sign-in
    installer/SignalLight.iss installs to %LOCALAPPDATA%\Programs\SignalLight
    with PrivilegesRequired=lowest (no UAC prompt), adds a Start menu
    shortcut, an optional HKCU Run entry to start at sign-in, and an
    uninstaller that closes the running app and asks whether to keep the
    pairing/settings. The release workflow now compiles it and signs both
    Setup and the uninstaller through the same Azure Trusted Signing tool,
    verifies the signature, and attaches SignalLight-Setup-<version>.exe
    alongside signallight.exe.
    App changes the installer depends on:
    - Release builds use -H=windowsgui, so starting at sign-in doesn't open
    a console win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
2026-10-02 docs: plan Bluetooth firmware updates and add roadmap TODOs
    docs/FIRMWARE_UPDATES.md records the design for updating the light's
    firmware from the Windows app over BLE: a small chunk/ack protocol on
    the existing ArduinoBLE stack using the core's Update library, firmware
    from GitHub Releases or a manual .bin upload, click-to-install, SHA-256
    verification, and the rollback self-check needed because the Arduino
    core otherwise confirms new images before setup() runs. Firmware signing,
    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
2026-10-02 test: BLE throughput prototype for firmware updates, with results
    Adds arduino/BleThroughputTest (test sketch: numbered chunks, FNV-1a
    checksum, cumulative ACKs, optional writes to the spare OTA slot that are
    always discarded) and windows/cmd/blethroughput (sends 128KB per mode and
    reports speed and integrity).
    Results on a Nano ESP32 and Windows 11: MTU 242; acked writes manage
    only 2 KB/s, while WriteWithoutResponse with a 32-chunk window reaches
    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
2026-10-02 feat: report firmware version; verify the light's reply when pairing
    Firmware version: the sketch exposes a read-only characteristic
    (19B10003) holding SIGNALLIGHT_VERSION ("dev" for IDE builds; release
    builds can set it via compiler.cpp.extra_flags). The Windows app reads it
    at the start of each session, /api/status includes firmware_version, and
    the dashboard shows it. Characteristic discovery is now unfiltered: the
    BLE library fails the whole lookup if any filtered UUID is missing, which
    would have stopped the app connecting to (and so updating) older firmware.
    Pairing: PairDevice used to sleep 400ms and treat the light as paired
    regardless of its reply, so ERR:ALREADY_PAIRED saved a pai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
    [SignalLight.ino]
2026-10-02 ci: compile the light's firmware and attach it to releases
    New firmware job (ubuntu) installs arduino-cli 1.5.1 with the same
    pinned core (arduino:esp32@2.0.18-arduino.5) and ArduinoBLE 2.1.0 used
    for local builds, compiles arduino/SignalLight with SIGNALLIGHT_VERSION
    set from the tag (0.0.0-dev.N for manual runs), fails if the version
    string isn't in the binary, and publishes signallight-firmware-<ver>.bin
    (the app image an OTA update writes) plus a .sha256. The Windows job
    waits for it and attaches the firmware alongside the exe and installer.
2026-10-02 feat: install firmware on the light over Bluetooth
    The light accepts a firmware image from an authenticated app on three new
    characteristics (control 19B10004, status 19B10005, data 19B10006): BEGIN
    with size and SHA-256, in-order chunks with an ACK every 16, then END. It
    verifies the hash, installs into the spare slot, and reboots. New firmware
    rolls back unless an authenticated connection confirms it within 5 minutes.
    The onboard LED shows blue during an update; the external light keeps its
    color.
    Windows side: the windows/ota package (window of 32 chunks, driven only by
    the light's ACKs) with tests against a simulated light, and a test tool,
    go run ./cmd/otaflash <firmware.bin>.
    Tested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
    [SignalLight.ino]
2026-10-02 feat: update the light's firmware from the dashboard
    The dashboard's firmware panel shows the light's version, checks GitHub
    Releases for the newest release with firmware attached (only while the
    dashboard is open: every 6 hours or on "Check for updates"), and installs
    it with one click. "Install from file..." sends a local build. Downloads
    are checked against the published SHA-256, progress follows the light's
    ACKs, and after the reboot the app waits for the light to reconnect on
    the new version and reports the result.
    The transfer runs in ble.Client's connection loop on the session's WinRT
    thread, pausing heartbeats for its ~10 seconds, so SignalLight no longer
    has to be quit. The privacy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

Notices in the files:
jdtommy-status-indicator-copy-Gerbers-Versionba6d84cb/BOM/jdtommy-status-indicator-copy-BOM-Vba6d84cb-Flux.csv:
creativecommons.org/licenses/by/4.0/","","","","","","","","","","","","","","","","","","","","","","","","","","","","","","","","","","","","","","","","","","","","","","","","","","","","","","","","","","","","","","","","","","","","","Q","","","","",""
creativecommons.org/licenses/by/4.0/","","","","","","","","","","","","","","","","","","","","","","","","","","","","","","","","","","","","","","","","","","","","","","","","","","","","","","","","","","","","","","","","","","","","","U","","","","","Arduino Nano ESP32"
